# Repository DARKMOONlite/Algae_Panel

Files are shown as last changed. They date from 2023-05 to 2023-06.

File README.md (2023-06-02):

# Algae_Panel
repo for the storage of files related to the control and operation of an Algae Bio-panel at UTS

## [CAD ](/CAD/README.md)
### **Contains:**
- Solidworks Files
- STLs
- Drawings & Assembly Diagrams 
- Product Information

## [Software ](/Software/README.md)
### **Contains:**
- Installation & Setup Guide
- Doxygen Documentation
- Tips for making modifications & using placed systems.

---
### Visual Layout of Repo

```mermaid

graph LR;
    Repo-->CAD;
    Repo-->Software;
    CAD-->1[ElectrialModels];
    CAD-->2[Plumbing];
    CAD-->3[Previous DMMS Group];
    CAD-->4[Pump & Elec Mount];
    CAD-->5[Interior Mounts];
    Software-->Deprecated;
    Software-->AlgaeProject;
    AlgaeProject-->src;
    AlgaeProject-->lib;
    AlgaeProject-->include;
```

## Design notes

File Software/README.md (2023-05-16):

## Setup and installation

### 1. Setup VSCode & PlatformIO
1. download VSCode from the [link provided](https://code.visualstudio.com/).
2. once downloaded, run or open via cli using the `code` function.

3. Ensure you have access to a C Compiler, if not then follow [this tutorial](https://code.visualstudio.com/docs/languages/cpp) on the topic

4. once open, select the extensions tab, search and install the PlatformIO extension.

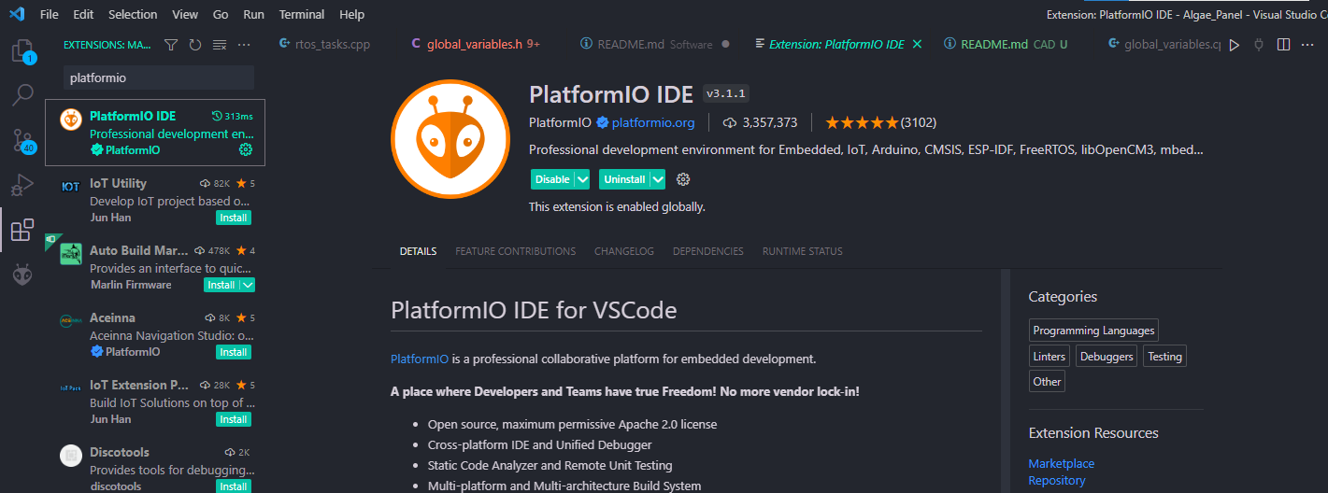
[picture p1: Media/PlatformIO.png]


5. Once downloaded open the [Algae Panel folder](/Software/Algae%20Project/) inside the Software folder inside the Algae Panel repo. this can be done via ```ctrl+K -> ctrl+O ```

6. Once done you should see the platformIO symbol in the primary bar  as well as a lot of new buttons down in the status bar.

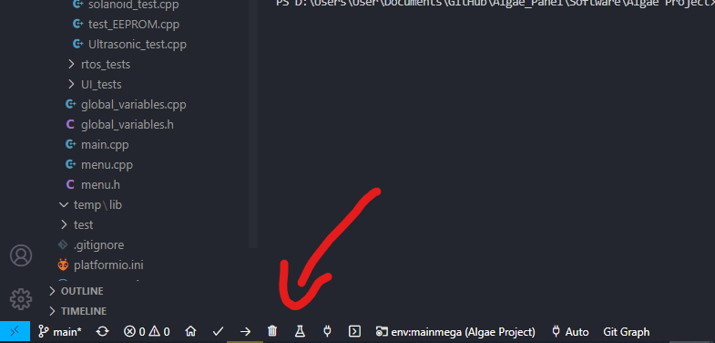
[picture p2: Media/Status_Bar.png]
 

These buttons starting from the tick do the following

| Symbol | Image | Description  |
| --- | --- |  ---- |
| Tick |  | builds the currently selected environment  |
| Arrow  |  | builds then uploads the selected environment to an attached board  |
| Trashcan  |  | cleans the currently attached arduino, replacing any code with a blink script  |
| Beaker  |  | runs all defined unit tests  |
| Plug  |  | Creates serial terminal connected to arduino  |
| terminal  |  | Creates a blank terminal (not very useful) |
| folder  |  | allows you to select the environment to build  |

---

## To run code
- create a new environment (inside the [platformio.ini file](/Software/Algae%20Project/platformio.ini)) or select a prexisting environment
- connect arduino to computer
- Upload the selected environment to the arduino via the Arrow Icon 

### Tips & Tricks

- if you're struggling to upload the file
    - ensure that no other terminal has access to the COM port (Open Serial Terminals are an often point of error)

    - if the arduino is constantly sending a stream of serial data back, you can press the power button to reset, then quickly upload before the arduino starts sending serial data

    - restart your computer

    - try another arduino

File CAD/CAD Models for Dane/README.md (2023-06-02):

READ ME

- Files ending in title ".WIP" are those that are: Work in Progress

- One file is an exploded Assembly

- One other file is a drawing file with BoM of different parts
- Furthermore you make need to zoom into .pdf in order to see the exploded parts

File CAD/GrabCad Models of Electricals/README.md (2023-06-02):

READ ME

- the following models in this file were downloaded from GrabCAD

- be aware that some of the models are outdated in terms of where the placement of the screw-in holes are

- this has affected the 3D print .STL file: FIXED_inside_mount

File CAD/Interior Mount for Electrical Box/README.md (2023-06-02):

READ ME

- file nameed: FIXED_inside_mount.SLDPRT is the best model for 3D printing:
- Be aware that the silos made will need to be reconfigured for each electrical component
- This is because the grabCAD models are not up to date as found out when the part was 3D printed
- Recommended to measure the screw-in holes on each electrical component & then reconfigure the file "FIXED_inside_mount" to new updated 

- File "Practice Assembly1" provides a visual layout of where each electrical component will sit on each silo. As previously stated if needed to be used for practical purposes, recommended that model is updated. 

- Schematics are provided. For further schematics of the electrical box itself, see link below: 
https://www.farnell.com/datasheets/1707001.pdf

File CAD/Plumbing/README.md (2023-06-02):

READ ME
- files added here are seperated into each folder based on the component
- furthermore there is a drawing provided for each one
- The majority of the components here were purchased at bunnings, some however needed to be purchased from specialty plumbing stores.
- Clear Hoses were used as its easy to see the flow of fluids through them, they do however have a low recomended maximum temperature limit, so in the future should be swapped for more robust piping.

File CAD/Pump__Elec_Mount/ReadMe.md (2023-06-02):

- This model is a simple design to affix the electrical box and the pump to the algae panel via hose clamps. 
- [This hose clamp](https://www.bunnings.com.au/kinetic-105-127mm-304-stainless-steel-hose-clamp_p0110744) was used, however it slightly too big, so a smaller one could be used instead.
- This model is effective however repeated installation and removal found that the design is quite weak, it could be redesigned an/or printed with a stronger material to make up for these discovered inefficiencies.

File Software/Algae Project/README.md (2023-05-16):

## A list of files has been proided as well as a short description on what they do and why/when you would want to make changes
---

| File | Description |
| --- | --- |
| [main.cpp](/Software/Algae%20Project/src/main.cpp) | Contains all running code|
| [menu.hpp/cpp](/Software/Algae%20Project/src/menu.h) | Contains definitions and declarations of menu system, custom functions related to the use of the menu are also placed here, if you want to add/rearrange the menu, it can be done by editing the menu class structure found here|
| [global_variables.h/cpp](/Software/Algae%20Project/src/global_variables.h) | Contains all global variable that need to be accessed from all other files, this includes EEPROM variables which should be defined here|
| [AlgaePanelRemote.hpp](/Software/Algae%20Project/include/AlgaePanelRemote.hpp) | Contains all definitions connected to controlling panel via remote, if you want to change remote, or add custom commands, you can do that by defining them here then using this inside the main switch case inside of main|
| [pin_definitions.hpp](/Software/Algae%20Project/include/pin_definitions.hpp) | Contains all pin defintions, if you want to add new sensors using new pins or change what pins are currently being used, add/modify them here (ensure that new pin has all needed functionality, etc: PWM, Analog In) |

## Libraries, there are 2 types of libraries used, platformIO maintained and User maintained.

- ### PlatformIO libraries can be found by opening the PlatformIO Homepage, then selecting Libraries in the lefthand submenu. 
    - These libraries have their own repositories that can be explored to view tutorials and examples on their use.
- ### Local libraries can be found inside the lib folder, the following is a list of libraries and their uses.

| Name | Description |
| --- | --- |
| DRI0050 | Manages the DRI0050 Pump PWM Controller |
| DS18B20 | Taken from Dane's original project, this reads the temperature of a one-wire temperature sensor |
| EEPPROM_Manager | contains an EEPROM_Variable and Manager class that allows for easier read write access to EEPROM memory |
| Simple_Menu | Contains a library that greatly simplifies menu creation and management, allows for variable modification and function calls |

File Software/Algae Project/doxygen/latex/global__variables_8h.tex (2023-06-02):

\hypertarget{global__variables_8h}{}\doxysection{src/global\+\_\+variables.h File Reference}
\label{global__variables_8h}\index{src/global\_variables.h@{src/global\_variables.h}}

Declares global variables to be used throughout the code.  

{\ttfamily \#include $<$Wire.\+h$>$}\newline
{\ttfamily \#include $<$Liquid\+Crystal\+\_\+\+I2\+C.\+h$>$}\newline
{\ttfamily \#include $<$Arduino\+STL.\+h$>$}\newline
{\ttfamily \#include $<$EEPROM\+\_\+\+Manager.\+h$>$}\newline
{\ttfamily \#include $<$menu.\+h$>$}\newline
{\ttfamily \#include $<$New\+Ping.\+h$>$}\newline
{\ttfamily \#include $<$DRI0050.\+h$>$}\newline
{\ttfamily \#include $<$Software\+Serial.\+h$>$}\newline
{\ttfamily \#include $<$DS18\+B20.\+h$>$}\newline
{\ttfamily \#include $<$pin\+\_\+definitions.\+hpp$>$}\newline
{\ttfamily \#include $<$Algae\+Panel\+Remote.\+hpp$>$}\newline
\doxysubsection*{Macros}
\begin{DoxyCompactItemize}
\item 
\#define \mbox{\hyperlink{global__variables_8h_a51cb8b878986ce3ff33493d99d02d7fc}{STATE\+\_\+\+RATE}}~2000
\item 
\#define \mbox{\hyperlink{global__variables_8h_a8c2953801f2011dc5901884b0e53ddd5}{SENSOR\+\_\+\+RATE}}~500
\item 
\#define \mbox{\hyperlink{global__variables_8h_a669d5bc07ca8e20ac1699a0b54db4817}{LCD\+\_\+\+RATE}}~500
\end{DoxyCompactItemize}
\doxysubsection*{Enumerations}
\begin{DoxyCompactItemize}
\item 
enum \mbox{\hyperlink{global__variables_8h_a7131f3b3e5d9a4980752d9ac3edaeea0}{Control\+\_\+\+State}} \{ \mbox{\hyperlink{global__variables_8h_a7131f3b3e5d9a4980752d9ac3edaeea0ad8a892b94d3a94ea861543c085ae782b}{Off}} =0
, \mbox{\hyperlink{global__variables_8h_a7131f3b3e5d9a4980752d9ac3edaeea0acad5010fb34447633f3139d69698a0f0}{Manual}} = 1
, \mbox{\hyperlink{global__variables_8h_a7131f3b3e5d9a4980752d9ac3edaeea0a9248ea5dc540b00adb523d1b86fc1389}{Automatic}} =2
 \}
\begin{DoxyCompactList}\small\item\em Control state for pump and solanoid. \end{DoxyCompactList}\end{DoxyCompactItemize}
\doxysubsection*{Variables}
\begin{DoxyCompactItemize}
\item 
const int \mbox{\hyperlink{global__variables_8h_ae0d7b8a179a4e00492f385d3e4c28875}{Cyclic\+\_\+\+Array\+\_\+\+Size}} = 10
\begin{DoxyCompactList}\small\item\em Cyclic\+\_\+\+Array Size;. \end{DoxyCompactList}\item 
uint8\+\_\+t \mbox{\hyperlink{global__variables_8h_a903dc10003a218620ea6bd4b59aca90f}{Cyclic\+\_\+\+Array\+\_\+\+Index}}
\begin{DoxyCompactList}\small\item\em Current Index of Arrays. \end{DoxyCompactList}\item 
int \mbox{\hyperlink{global__variables_8h_a4aa978fdd8b2af0060581b4cf057aa15}{Temp1}} \mbox{[}\mbox{\hyperlink{global__variables_8h_ae0d7b8a179a4e00492f385d3e4c28875}{Cyclic\+\_\+\+Array\+\_\+\+Size}}\mbox{]}
\item 
int \mbox{\hyperlink{global__variables_8h_a349ef976a3c80acee90c13d5274c1012}{Temp2}} \mbox{[}\mbox{\hyperlink{global__variables_8h_ae0d7b8a179a4e00492f385d3e4c28875}{Cyclic\+\_\+\+Array\+\_\+\+Size}}\mbox{]}
\item 
int \mbox{\hyperlink{global__variables_8h_a7a4f9da5a5b03e3b620a52b326c99171}{Sonar\+Dist1}} \mbox{[}\mbox{\hyperlink{global__variables_8h_ae0d7b8a179a4e00492f385d3e4c28875}{Cyclic\+\_\+\+Array\+\_\+\+Size}}\mbox{]}
\item 
int \mbox{\hyperlink{global__variables_8h_aa7423da4abe01b3d4e3ca46efe227ecc}{IRDist2}} \mbox{[}\mbox{\hyperlink{global__variables_8h_ae0d7b8a179a4e00492f385d3e4c28875}{Cyclic\+\_\+\+Array\+\_\+\+Size}}\mbox{]}
\item 
int \mbox{\hyperlink{global__variables_8h_ad2cddfbedfaa3c72c5ca3458123de2e6}{Temp1\+Average}}
\begin{DoxyCompactList}\small\item\em Current Rolling Average of value. \end{DoxyCompactList}\item 
int \mbox{\hyperlink{global__variables_8h_a98a9f68d7aba6c3f37ea78974a6cc324}{Temp2\+Average}}
\item 
int \mbox{\hyperlink{global__variables_8h_af8fa803a5d79a542c42ff09091f99f4c}{Sonar\+Average}}
\item 
int \mbox{\hyperlink{global__variables_8h_ac2983004a8cc1f5eade6ee043f323f2f}{IRAverage}}
\item 
\mbox{\hyperlink{global__variables_8h_a7131f3b3e5d9a4980752d9ac3edaeea0}{Control\+\_\+\+State}} \mbox{\hyperlink{global__variables_8h_a2192d4871d46cdc3fba65146088bdcb9}{Pump\+State}}
\item 
\mbox{\hyperlink{global__variables_8h_a7131f3b3e5d9a4980752d9ac3edaeea0}{Control\+\_\+\+State}} \mbox{\hyperlink{global__variables_8h_a73b179801e50a86199223fbf88f5c12e}{Solanoid\+State}}
\item 
\mbox{\hyperlink{global__variables_8h_a7131f3b3e5d9a4980752d9ac3edaeea0}{Control\+\_\+\+State}} \mbox{\hyperlink{global__variables_8h_a430bb6acf8cdf613e077c6a7f7c3d015}{prev\+Pump\+State}}
\item 
\mbox{\hyperlink{global__variables_8h_a7131f3b3e5d9a4980752d9ac3edaeea0}{Control\+\_\+\+State}} \mbox{\hyperlink{global__variables_8h_a48b73615b2cf62582fb4c47f95971475}{prev\+Solanoid\+State}}
\item 
uint32\+\_\+t \mbox{\hyperlink{global__variables_8h_a17ca7918be207c977093defdb63d0867}{last\+State\+Update}}
\item 
uint32\+\_\+t \mbox{\hyperlink{global__variables_8h_a549b506ca4e238d975211948ab268d2f}{last\+LCDUpdate}}
\item 
uint32\+\_\+t \mbox{\hyperlink{global__variables_8h_ae7075b28a1b0396f31bba96665f4e903}{last\+Sensor\+Update}}
\item 
Liquid\+Crystal\+\_\+\+I2C \mbox{\hyperlink{global__variables_8h_a0b3886fc5d22cd9c3db5f0da7b01a2ce}{lcd}}
\item 
\mbox{\hyperlink{class_e_e_p_r_o_m___manager}{EEPROM\+\_\+\+Manager}} \mbox{\hyperlink{global__variables_8h_ab06c714ee161cf34440fdb53fb5a6d24}{rom\+\_\+manager}}
\item 
\mbox{\hyperlink{class_e_e_p_r_o_m___variable}{EEPROM\+\_\+\+Variable}} \mbox{\hyperlink{global__variables_8h_a306cb999495057968c9ebdaca2d99c44}{manual\+\_\+dutycycle}}
\item 
\mbox{\hyperlink{class_e_e_p_r_o_m___variable}{EEPROM\+\_\+\+Variable}} \mbox{\hyperlink{global__variables_8h_a4402b0cf0598116bc1d727b00c74bf51}{autosave}}
\end{DoxyCompactItemize}

\doxysubsection{Detailed Description}
Declares global variables to be used throughout the code. 

\begin{DoxyAuthor}{Author}
your name (\href{mailto:you@domain.com}{\texttt{ you@domain.\+com}}) 
\end{DoxyAuthor}
\begin{DoxyVersion}{Version}
0.\+1 
\end{DoxyVersion}
\begin{DoxyDate}{Date}
2023-\/06-\/02
\end{DoxyDate}
\begin{DoxyCopyright}{Copyright}
Copyright (c) 2023 
\end{DoxyCopyright}

\doxysubsection{Macro Definition Documentation}
\mbox{\Hypertarget{global__variables_8h_a669d5bc07ca8e20ac1699a0b54db4817}\label{global__variables_8h_a669d5bc07ca8e20ac1699a0b54db4817}} 
\index{global\_variables.h@{global\_variables.h}!LCD\_RATE@{LCD\_RATE}}
\index{LCD\_RATE@{LCD\_RATE}!global\_variables.h@{global\_variables.h}}
\doxysubsubsection{\texorpdfstring{LCD\_RATE}{LCD\_RATE}}
{\footnotesize\ttfamily \#define LCD\+\_\+\+RATE~500}

\mbox{\Hypertarget{global__variables_8h_a8c2953801f2011dc5901884b0e53ddd5}\label{global__variables_8h_a8c2953801f2011dc5901884b0e53ddd5}} 
\index{global\_variables.h@{global\_variables.h}!SENSOR\_RATE@{SENSOR\_RATE}}
\index{SENSOR\_RATE@{SENSOR\_RATE}!global\_variables.h@{global\_variables.h}}
\doxysubsubsection{\texorpdfstring{SENSOR\_RATE}{SENSOR\_RATE}}
{\footnotesize\ttfamily \#define SENSOR\+\_\+\+RATE~500}

\mbox{\Hypertarget{global__variables_8h_a51cb8b878986ce3ff33493d99d02d7fc}\label{global__variables_8h_a51cb8b878986ce3ff33493d99d02d7fc}} 
\index{global\_variables.h@{global\_variables.h}!STATE\_RATE@{STATE\_RATE}}
\index{STATE\_RATE@{STATE\_RATE}!global\_variables.h@{global\_variables.h}}
\doxysubsubsection{\texorpdfstring{STATE\_RATE}{STATE\_RATE}}
{\footnotesize\ttfamily \#define STATE\+\_\+\+RATE~2000}

\doxysubsection{Enumeration Type Documentation}
\mbox{\Hypertarget{global__variables_8h_a7131f3b3e5d9a4980752d9ac3edaeea0}\label{global__variables_8h_a7131f3b3e5d9a4980752d9ac3edaeea0}} 
\index{global\_variables.h@{global\_variables.h}!Control\_State@{Control\_State}}
\index{Control\_State@{Control\_State}!global\_variables.h@{global\_variables.h}}
\doxysubsubsection{\texorpdfstring{Control\_State}{Control\_State}}
{\footnotesize\ttfamily enum \mbox{\hyperlink{global__variables_8h_a7131f3b3e5d9a4980752d9ac3edaeea0}{Control\+\_\+\+State}}}

Control state for pump and solanoid. 

\begin{DoxyEnumFields}{Enumerator}
\raisebox{\heightof{T}}[0pt][0pt]{\index{Off@{Off}!global\_variables.h@{global\_variables.h}}\index{global\_variables.h@{global\_variables.h}!Off@{Off}}}\mbox{\Hypertarget{global__variables_8h_a7131f3b3e5d9a4980752d9ac3edaeea0ad8a892b94d3a94ea861543c085ae782b}\label{global__variables_8h_a7131f3b3e5d9a4980752d9ac3edaeea0ad8a892b94d3a94ea861543c085ae782b}} 
Off&\\
\hline

\raisebox{\heightof{T}}[0pt][0pt]{\index{Manual@{Manual}!global\_variables.h@{global\_variables.h}}\index{global\_variables.h@{global\_variables.h}!Manual@{Manual}}}\mbox{\Hypertarget{global__variables_8h_a7131f3b3e5d9a4980752d9ac3edaeea0acad5010fb34447633f3139d69698a0f0}\label{global__variables_8h_a7131f3b3e5d9a4980752d9ac3edaeea0acad5010fb34447633f3139d69698a0f0}} 
Manual&\\
\hline

\raisebox{\heightof{T}}[0pt][0pt]{\index{Automatic@{Automatic}!global\_variables.h@{global\_variables.h}}\index{global\_variables.h@{global\_variables.h}!Automatic@{Automatic}}}\mbox{\Hypertarget{global__variables_8h_a7131f3b3e5d9a4980752d9ac3edaeea0a9248ea5dc540b00adb523d1b86fc1389}\label{global__variables_8h_a7131f3b3e5d9a4980752d9ac3edaeea0a9248ea5dc540b00adb523d1b86fc1389}} 
Automatic&\\
\hline

\end{DoxyEnumFields}

\doxysubsection{Variable Documentation}
\mbox{\Hypertarget{global__variables_8h_a4402b0cf0598116bc1d727b00c74bf51}\label{global__variables_8h_a4402b0cf0598116bc1d727b00c74bf51}} 
\index{global\_variables.h@{global\_variables.h}!autosave@{autosave}}
\index{autosave@{autosave}!global\_variables.h@{global\_variables.h}}
\doxysubsubsection{\texorpdfstring{autosave}{autosave}}
{\footnotesize\ttfamily \mbox{\hyperlink{class_e_e_p_r_o_m___variable}{EEPROM\+\_\+\+Variable}} autosave\hspace{0.3cm}{\ttfamily [extern]}}

\mbox{\Hypertarget{global__variables_8h_a903dc10003a218620ea6bd4b59aca90f}\label{global__variables_8h_a903dc10003a218620ea6bd4b59aca90f}} 
\index{global\_variables.h@{global\_variables.h}!Cyclic\_Array\_Index@{Cyclic\_Array\_Index}}
\index{Cyclic\_Array\_Index@{Cyclic\_Array\_Index}!global\_variables.h@{global\_variables.h}}
\doxysubsubsection{\texorpdfstring{Cyclic\_Array\_Index}{Cyclic\_Array\_Index}}
{\footnotesize\ttfamily uint8\+\_\+t Cyclic\+\_\+\+Array\+\_\+\+Index\hspace{0.3cm}{\ttfamily [extern]}}

Current Index of Arrays. 

\mbox{\Hypertarget{global__variables_8h_ae0d7b8a179a4e00492f385d3e4c28875}\label{global__variables_8h_ae0d7b8a179a4e00492f385d3e4c28875}} 
\index{global\_variables.h@{global\_variables.h}!Cyclic\_Array\_Size@{Cyclic\_Array\_Size}}
\index{Cyclic\_Array\_Size@{Cyclic\_Array\_Size}!global\_variables.h@{global\_variables.h}}
\doxysubsubsection{\texorpdfstring{Cyclic\_Array\_Size}{Cyclic\_Array\_Size}}
{\footnotesize\ttfamily const int Cyclic\+\_\+\+Array\+\_\+\+Size = 10}

Cyclic\+\_\+\+Array Size;. 

\mbox{\Hypertarget{global__variables_8h_ac2983004a8cc1f5eade6ee043f323f2f}\label{global__variables_8h_ac2983004a8cc1f5eade6ee043f323f2f}} 
\index{global\_variables.h@{global\_variables.h}!IRAverage@{IRAverage}}
\index{IRAverage@{IRAverage}!global\_variables.h@{global\_variables.h}}
\doxysubsubsection{\texorpdfstring{IRAverage}{IRAverage}}
{\footnotesize\ttfamily int IRAverage}

\mbox{\Hypertarget{global__variables_8h_aa7423da4abe01b3d4e3ca46efe227ecc}\label{global__variables_8h_aa7423da4abe01b3d4e3ca46efe227ecc}} 
\index{global\_variables.h@{global\_variables.h}!IRDist2@{IRDist2}}
\index{IRDist2@{IRDist2}!global\_variables.h@{global\_variables.h}}
\doxysubsubsection{\texorpdfstring{IRDist2}{IRDist2}}
{\footnotesize\ttfamily int IRDist2\mbox{[}\mbox{\hyperlink{global__variables_8h_ae0d7b8a179a4e00492f385d3e4c28875}{Cyclic\+\_\+\+Array\+\_\+\+Size}}\mbox{]}}

\mbox{\Hypertarget{global__variables_8h_a549b506ca4e238d975211948ab268d2f}\label{global__variables_8h_a549b506ca4e238d975211948ab268d2f}} 
\index{global\_variables.h@{global\_variables.h}!lastLCDUpdate@{lastLCDUpdate}}
\index{lastLCDUpdate@{lastLCDUpdate}!global\_variables.h@{global\_variables.h}}
\doxysubsubsection{\texorpdfstring{lastLCDUpdate}{lastLCDUpdate}}
{\footnotesize\ttfamily uint32\+\_\+t last\+LCDUpdate}

\mbox{\Hypertarget{global__variables_8h_ae7075b28a1b0396f31bba96665f4e903}\label{global__variables_8h_ae7075b28a1b0396f31bba96665f4e903}} 
\index{global\_variables.h@{global\_variables.h}!lastSensorUpdate@{lastSensorUpdate}}
\index{lastSensorUpdate@{lastSensorUpdate}!global\_variables.h@{global\_variables.h}}
\doxysubsubsection{\texorpdfstring{lastSensorUpdate}{lastSensorUpdate}}
{\footnotesize\ttfamily uint32\+\_\+t last\+Sensor\+Update}

\mbox{\Hypertarget{global__variables_8h_a17ca7918be207c977093defdb63d0867}\label{global__variables_8h_a17ca7918be207c977093defdb63d0867}} 
\index{global\_variables.h@{global\_variables.h}!lastStateUpdate@{lastStateUpdate}}
\index{lastStateUpdate@{lastStateUpdate}!global\_variables.h@{global\_variables.h}}
\doxysubsubsection{\texorpdfstring{lastStateUpdate}{lastStateUpdate}}
{\footnotesize\ttfamily uint32\+\_\+t last\+State\+Update\hspace{0.3cm}{\ttfamily [extern]}}

\mbox{\Hypertarget{global__variables_8h_a0b3886fc5d22cd9c3db5f0da7b01a2ce}\label{global__variables_8h_a0b3886fc5d22cd9c3db5f0da7b01a2ce}} 
\index{global\_variables.h@{global\_variables.h}!lcd@{lcd}}
\index{lcd@{lcd}!global\_variables.h@{global\_variables.h}}
\doxysubsubsection{\texorpdfstring{lcd}{lcd}}
{\footnotesize\ttfamily Liquid\+Crystal\+\_\+\+I2C lcd\hspace{0.3cm}{\ttfamily [extern]}}

\mbox{\Hypertarget{global__variables_8h_a306cb999495057968c9ebdaca2d99c44}\label{global__variables_8h_a306cb999495057968c9ebdaca2d99c44}} 
\index{global\_variables.h@{global\_variables.h}!manual\_dutycycle@{manual\_dutycycle}}
\index{manual\_dutycycle@{manual\_dutycycle}!global\_variables.h@{global\_variables.h}}
\doxysubsubsection{\texorpdfstring{manual\_dutycycle}{manual\_dutycycle}}
{\footnotesize\ttfamily \mbox{\hyperlink{class_e_e_p_r_o_m___variable}{EEPROM\+\_\+\+Variable}} manual\+\_\+dutycycle\hspace{0.3cm}{\ttfamily [extern]}}

\mbox{\Hypertarget{global__variables_8h_a430bb6acf8cdf613e077c6a7f7c3d015}\label{global__variables_8h_a430bb6acf8cdf613e077c6a7f7c3d015}} 
\index{global\_variables.h@{global\_variables.h}!prevPumpState@{prevPumpState}}
\index{prevPumpState@{prevPumpState}!global\_variables.h@{global\_variables.h}}
\doxysubsubsection{\texorpdfstring{prevPumpState}{prevPumpState}}
{\footnotesize\ttfamily \mbox{\hyperlink{global__variables_8h_a7131f3b3e5d9a4980752d9ac3edaeea0}{Control\+\_\+\+State}} prev\+Pump\+State}

\mbox{\Hypertarget{global__variables_8h_a48b73615b2cf62582fb4c47f95971475}\label{global__variables_8h_a48b73615b2cf62582fb4c47f95971475}} 
\index{global\_variables.h@{global\_variables.h}!prevSolanoidState@{prevSolanoidState}}
\index{prevSolanoidState@{prevSolanoidState}!global\_variables.h@{global\_variables.h}}
\doxysubsubsection{\texorpdfstring{prevSolanoidState}{prevSolanoidState}}
{\footnotesize\ttfamily \mbox{\hyperlink{global__variables_8h_a7131f3b3e5d9a4980752d9ac3edaeea0}{Control\+\_\+\+State}} prev\+Solanoid\+State}

\mbox{\Hypertarget{global__variables_8h_a2192d4871d46cdc3fba65146088bdcb9}\label{global__variables_8h_a2192d4871d46cdc3fba65146088bdcb9}} 
\index{global\_variables.h@{global\_variables.h}!PumpState@{PumpState}}
\index{PumpState@{PumpState}!global\_variables.h@{global\_variables.h}}
\doxysubsubsection{\texorpdfstring{PumpState}{PumpState}}
{\footnotesize\ttfamily \mbox{\hyperlink{global__variables_8h_a7131f3b3e5d9a4980752d9ac3edaeea0}{Control\+\_\+\+State}} Pump\+State\hspace{0.3cm}{\ttfamily [extern]}}

\mbox{\Hypertarget{global__variables_8h_ab06c714ee161cf34440fdb53fb5a6d24}\label{global__variables_8h_ab06c714ee161cf34440fdb53fb5a6d24}} 
\index{global\_variables.h@{global\_variables.h}!rom\_manager@{rom\_manager}}
\index{rom\_manager@{rom\_manager}!global\_variables.h@{global\_variables.h}}
\doxysubsubsection{\texorpdfstring{rom\_manager}{rom\_manager}}
{\footnotesize\ttfamily \mbox{\hyperlink{class_e_e_p_r_o_m___manager}{EEPROM\+\_\+\+Manager}} rom\+\_\+manager\hspace{0.3cm}{\ttfamily [extern]}}

\mbox{\Hypertarget{global__variables_8h_a73b179801e50a86199223fbf88f5c12e}\label{global__variables_8h_a73b179801e50a86199223fbf88f5c12e}} 
\index{global\_variables.h@{global\_variables.h}!SolanoidState@{SolanoidState}}
\index{SolanoidState@{SolanoidState}!global\_variables.h@{global\_variables.h}}
\doxysubsubsection{\texorpdfstring{SolanoidState}{SolanoidState}}
{\footnotesize\ttfamily \mbox{\hyperlink{global__variables_8h_a7131f3b3e5d9a4980752d9ac3edaeea0}{Control\+\_\+\+State}} Solanoid\+State}

\mbox{\Hypertarget{global__variables_8h_af8fa803a5d79a542c42ff09091f99f4c}\label{global__variables_8h_af8fa803a5d79a542c42ff09091f99f4c}} 
\index{global\_variables.h@{global\_variables.h}!SonarAverage@{SonarAverage}}
\index{SonarAverage@{SonarAverage}!global\_variables.h@{global\_variables.h}}
\doxysubsubsection{\texorpdfstring{SonarAverage}{SonarAverage}}
{\footnotesize\ttfamily int Sonar\+Average}

\mbox{\Hypertarget{global__variables_8h_a7a4f9da5a5b03e3b620a52b326c99171}\label{global__variables_8h_a7a4f9da5a5b03e3b620a52b326c99171}} 
\index{global\_variables.h@{global\_variables.h}!SonarDist1@{SonarDist1}}
\index{SonarDist1@{SonarDist1}!global\_variables.h@{global\_variables.h}}
\doxysubsubsection{\texorpdfstring{SonarDist1}{SonarDist1}}
{\footnotesize\ttfamily int Sonar\+Dist1\mbox{[}\mbox{\hyperlink{global__variables_8h_ae0d7b8a179a4e00492f385d3e4c28875}{Cyclic\+\_\+\+Array\+\_\+\+Size}}\mbox{]}}

\mbox{\Hypertarget{global__variables_8h_a4aa978fdd8b2af0060581b4cf057aa15}\label{global__variables_8h_a4aa978fdd8b2af0060581b4cf057aa15}} 
\index{global\_variables.h@{global\_variables.h}!Temp1@{Temp1}}
\index{Temp1@{Temp1}!global\_variables.h@{global\_variables.h}}
\doxysubsubsection{\texorpdfstring{Temp1}{Temp1}}
{\footnotesize\ttfamily int Temp1\mbox{[}\mbox{\hyperlink{global__variables_8h_ae0d7b8a179a4e00492f385d3e4c28875}{Cyclic\+\_\+\+Array\+\_\+\+Size}}\mbox{]}\hspace{0.3cm}{\ttfamily [extern]}}

\mbox{\Hypertarget{global__variables_8h_ad2cddfbedfaa3c72c5ca3458123de2e6}\label{global__variables_8h_ad2cddfbedfaa3c72c5ca3458123de2e6}} 
\index{global\_variables.h@{global\_variables.h}!Temp1Average@{Temp1Average}}
\index{Temp1Average@{Temp1Average}!global\_variables.h@{global\_variables.h}}
\doxysubsubsection{\texorpdfstring{Temp1Average}{Temp1Average}}
{\footnotesize\ttfamily int Temp1\+Average\hspace{0.3cm}{\ttfamily [extern]}}

Current Rolling Average of value. 

\mbox{\Hypertarget{global__variables_8h_a349ef976a3c80acee90c13d5274c1012}\label{global__variables_8h_a349ef976a3c80acee90c13d5274c1012}} 
\index{global\_variables.h@{global\_variables.h}!Temp2@{Temp2}}
\index{Temp2@{Temp2}!global\_variables.h@{global\_variables.h}}
\doxysubsubsection{\texorpdfstring{Temp2}{Temp2}}
{\footnotesize\ttfamily int Temp2\mbox{[}\mbox{\hyperlink{global__variables_8h_ae0d7b8a179a4e00492f385d3e4c28875}{Cyclic\+\_\+\+Array\+\_\+\+Size}}\mbox{]}}

\mbox{\Hypertarget{global__variables_8h_a98a9f68d7aba6c3f37ea78974a6cc324}\label{global__variables_8h_a98a9f68d7aba6c3f37ea78974a6cc324}} 
\index{global\_variables.h@{global\_variables.h}!Temp2Average@{Temp2Average}}
\index{Temp2Average@{Temp2Average}!global\_variables.h@{global\_variables.h}}
\doxysubsubsection{\texorpdfstring{Temp2Average}{Temp2Average}}
{\footnotesize\ttfamily int Temp2\+Average}

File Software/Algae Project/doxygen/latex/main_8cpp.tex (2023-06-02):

\hypertarget{main_8cpp}{}\doxysection{src/main.cpp File Reference}
\label{main_8cpp}\index{src/main.cpp@{src/main.cpp}}

Main file, to run either select the main or mainmega environments inside platformio main may not run due to the large size of the menu inside.  

{\ttfamily \#include $<$Wire.\+h$>$}\newline
{\ttfamily \#include $<$global\+\_\+variables.\+h$>$}\newline
{\ttfamily \#include $<$Arduino.\+h$>$}\newline
{\ttfamily \#include $<$IRremote.\+h$>$}\newline
\doxysubsection*{Functions}
\begin{DoxyCompactItemize}
\item 
void \mbox{\hyperlink{main_8cpp_af9cf4ef7ebebb6c181594d5a1c6dc3a2}{Update\+\_\+\+Sensor\+\_\+\+State}} ()
\item 
void \mbox{\hyperlink{main_8cpp_a4be994af2b57ccfe32022694d07b4082}{Update\+\_\+\+Control\+\_\+\+State}} ()
\item 
New\+Ping \mbox{\hyperlink{main_8cpp_aa3890dc13ad641f783b713ac4bd4a749}{Sonar1}} (\mbox{\hyperlink{pin__definitions_8hpp_a9a54be5fe92c6d16578982bf6cecd891}{SSensor\+Pin1}}, \mbox{\hyperlink{pin__definitions_8hpp_aea99235fa3eef529e3ca42c55036d49a}{Sonar\+Echo\+Pin}}, 400)
\item 
New\+Ping \mbox{\hyperlink{main_8cpp_a13056dab98115394b132ce9e388cd66f}{Sonar2}} (\mbox{\hyperlink{pin__definitions_8hpp_acbebe49963630ffe7894925f9af6929e}{SSensor\+Pin2}}, \mbox{\hyperlink{pin__definitions_8hpp_aea99235fa3eef529e3ca42c55036d49a}{Sonar\+Echo\+Pin}}, 400)
\item 
IRrecv \mbox{\hyperlink{main_8cpp_a719f315363a42d399582066b011803a0}{irrecv}} (\mbox{\hyperlink{pin__definitions_8hpp_aca6f3616097e746f44b630d09fa99c98}{IRRXPin}})
\item 
void \mbox{\hyperlink{main_8cpp_a4fc01d736fe50cf5b977f755b675f11d}{setup}} ()
\item 
void \mbox{\hyperlink{main_8cpp_afe461d27b9c48d5921c00d521181f12f}{loop}} ()
\end{DoxyCompactItemize}
\doxysubsection*{Variables}
\begin{DoxyCompactItemize}
\item 
\mbox{\hyperlink{class_d_s18_b20}{DS18\+B20}} \mbox{\hyperlink{main_8cpp_abf193c5fdc2f45cdabb593b689213741}{Temp\+Sensor1}} (\mbox{\hyperlink{pin__definitions_8hpp_a671f1d97cbed333ba37efc31c19176d4}{TSensor\+Pin1}})
\item 
\mbox{\hyperlink{class_d_s18_b20}{DS18\+B20}} \mbox{\hyperlink{main_8cpp_ae6a8ea5c1f475f84c3a2fd12ccca81a1}{Temp\+Sensor2}} (\mbox{\hyperlink{pin__definitions_8hpp_a1b12e63467a86c1176ada2ca6dfd6ba1}{TSensor\+Pin2}})
\item 
\mbox{\hyperlink{class_d_r_i0050}{DRI0050}} \mbox{\hyperlink{main_8cpp_a8b8365b51c26f340cc7c21a6eddc1146}{Pump\+Controller}} (\mbox{\hyperlink{pin__definitions_8hpp_ae547f2a53633fd8b936d4dc812447c17}{Pump\+Tx\+Pin}}, \mbox{\hyperlink{pin__definitions_8hpp_a98300bbbce3a65d992bbf4be3a84600b}{Pump\+Rx\+Pin}})
\end{DoxyCompactItemize}

\doxysubsection{Detailed Description}
Main file, to run either select the main or mainmega environments inside platformio main may not run due to the large size of the menu inside. 

\begin{DoxyAuthor}{Author}
Sebastian Schroder 
\end{DoxyAuthor}

\doxysubsection{Function Documentation}
\mbox{\Hypertarget{main_8cpp_a719f315363a42d399582066b011803a0}\label{main_8cpp_a719f315363a42d399582066b011803a0}} 
\index{main.cpp@{main.cpp}!irrecv@{irrecv}}
\index{irrecv@{irrecv}!main.cpp@{main.cpp}}
\doxysubsubsection{\texorpdfstring{irrecv()}{irrecv()}}
{\footnotesize\ttfamily IRrecv irrecv (\begin{DoxyParamCaption}\item[{\mbox{\hyperlink{pin__definitions_8hpp_aca6f3616097e746f44b630d09fa99c98}{IRRXPin}}}]{ }\end{DoxyParamCaption})}

\mbox{\Hypertarget{main_8cpp_afe461d27b9c48d5921c00d521181f12f}\label{main_8cpp_afe461d27b9c48d5921c00d521181f12f}} 
\index{main.cpp@{main.cpp}!loop@{loop}}
\index{loop@{loop}!main.cpp@{main.cpp}}
\doxysubsubsection{\texorpdfstring{loop()}{loop()}}
{\footnotesize\ttfamily void loop (\begin{DoxyParamCaption}{ }\end{DoxyParamCaption})}

\mbox{\Hypertarget{main_8cpp_a4fc01d736fe50cf5b977f755b675f11d}\label{main_8cpp_a4fc01d736fe50cf5b977f755b675f11d}} 
\index{main.cpp@{main.cpp}!setup@{setup}}
\index{setup@{setup}!main.cpp@{main.cpp}}
\doxysubsubsection{\texorpdfstring{setup()}{setup()}}
{\footnotesize\ttfamily void setup (\begin{DoxyParamCaption}{ }\end{DoxyParamCaption})}

\mbox{\Hypertarget{main_8cpp_aa3890dc13ad641f783b713ac4bd4a749}\label{main_8cpp_aa3890dc13ad641f783b713ac4bd4a749}} 
\index{main.cpp@{main.cpp}!Sonar1@{Sonar1}}
\index{Sonar1@{Sonar1}!main.cpp@{main.cpp}}
\doxysubsubsection{\texorpdfstring{Sonar1()}{Sonar1()}}
{\footnotesize\ttfamily New\+Ping Sonar1 (\begin{DoxyParamCaption}\item[{\mbox{\hyperlink{pin__definitions_8hpp_a9a54be5fe92c6d16578982bf6cecd891}{SSensor\+Pin1}}}]{,  }\item[{\mbox{\hyperlink{pin__definitions_8hpp_aea99235fa3eef529e3ca42c55036d49a}{Sonar\+Echo\+Pin}}}]{,  }\item[{400}]{ }\end{DoxyParamCaption})}

\mbox{\Hypertarget{main_8cpp_a13056dab98115394b132ce9e388cd66f}\label{main_8cpp_a13056dab98115394b132ce9e388cd66f}} 
\index{main.cpp@{main.cpp}!Sonar2@{Sonar2}}
\index{Sonar2@{Sonar2}!main.cpp@{main.cpp}}
\doxysubsubsection{\texorpdfstring{Sonar2()}{Sonar2()}}
{\footnotesize\ttfamily New\+Ping Sonar2 (\begin{DoxyParamCaption}\item[{\mbox{\hyperlink{pin__definitions_8hpp_acbebe49963630ffe7894925f9af6929e}{SSensor\+Pin2}}}]{,  }\item[{\mbox{\hyperlink{pin__definitions_8hpp_aea99235fa3eef529e3ca42c55036d49a}{Sonar\+Echo\+Pin}}}]{,  }\item[{400}]{ }\end{DoxyParamCaption})}

\mbox{\Hypertarget{main_8cpp_a4be994af2b57ccfe32022694d07b4082}\label{main_8cpp_a4be994af2b57ccfe32022694d07b4082}} 
\index{main.cpp@{main.cpp}!Update\_Control\_State@{Update\_Control\_State}}
\index{Update\_Control\_State@{Update\_Control\_State}!main.cpp@{main.cpp}}
\doxysubsubsection{\texorpdfstring{Update\_Control\_State()}{Update\_Control\_State()}}
{\footnotesize\ttfamily void Update\+\_\+\+Control\+\_\+\+State (\begin{DoxyParamCaption}{ }\end{DoxyParamCaption})}

\mbox{\Hypertarget{main_8cpp_af9cf4ef7ebebb6c181594d5a1c6dc3a2}\label{main_8cpp_af9cf4ef7ebebb6c181594d5a1c6dc3a2}} 
\index{main.cpp@{main.cpp}!Update\_Sensor\_State@{Update\_Sensor\_State}}
\index{Update\_Sensor\_State@{Update\_Sensor\_State}!main.cpp@{main.cpp}}
\doxysubsubsection{\texorpdfstring{Update\_Sensor\_State()}{Update\_Sensor\_State()}}
{\footnotesize\ttfamily void Update\+\_\+\+Sensor\+\_\+\+State (\begin{DoxyParamCaption}{ }\end{DoxyParamCaption})}

\doxysubsection{Variable Documentation}
\mbox{\Hypertarget{main_8cpp_a8b8365b51c26f340cc7c21a6eddc1146}\label{main_8cpp_a8b8365b51c26f340cc7c21a6eddc1146}} 
\index{main.cpp@{main.cpp}!PumpController@{PumpController}}
\index{PumpController@{PumpController}!main.cpp@{main.cpp}}
\doxysubsubsection{\texorpdfstring{PumpController}{PumpController}}
{\footnotesize\ttfamily \mbox{\hyperlink{class_d_r_i0050}{DRI0050}} Pump\+Controller(\mbox{\hyperlink{pin__definitions_8hpp_ae547f2a53633fd8b936d4dc812447c17}{Pump\+Tx\+Pin}}, \mbox{\hyperlink{pin__definitions_8hpp_a98300bbbce3a65d992bbf4be3a84600b}{Pump\+Rx\+Pin}}) (\begin{DoxyParamCaption}\item[{\mbox{\hyperlink{pin__definitions_8hpp_ae547f2a53633fd8b936d4dc812447c17}{Pump\+Tx\+Pin}}}]{,  }\item[{\mbox{\hyperlink{pin__definitions_8hpp_a98300bbbce3a65d992bbf4be3a84600b}{Pump\+Rx\+Pin}}}]{ }\end{DoxyParamCaption})}

\mbox{\Hypertarget{main_8cpp_abf193c5fdc2f45cdabb593b689213741}\label{main_8cpp_abf193c5fdc2f45cdabb593b689213741}} 
\index{main.cpp@{main.cpp}!TempSensor1@{TempSensor1}}
\index{TempSensor1@{TempSensor1}!main.cpp@{main.cpp}}
\doxysubsubsection{\texorpdfstring{TempSensor1}{TempSensor1}}
{\footnotesize\ttfamily \mbox{\hyperlink{class_d_s18_b20}{DS18\+B20}} Temp\+Sensor1(\mbox{\hyperlink{pin__definitions_8hpp_a671f1d97cbed333ba37efc31c19176d4}{TSensor\+Pin1}}) (\begin{DoxyParamCaption}\item[{\mbox{\hyperlink{pin__definitions_8hpp_a671f1d97cbed333ba37efc31c19176d4}{TSensor\+Pin1}}}]{ }\end{DoxyParamCaption})}

\mbox{\Hypertarget{main_8cpp_ae6a8ea5c1f475f84c3a2fd12ccca81a1}\label{main_8cpp_ae6a8ea5c1f475f84c3a2fd12ccca81a1}} 
\index{main.cpp@{main.cpp}!TempSensor2@{TempSensor2}}
\index{TempSensor2@{TempSensor2}!main.cpp@{main.cpp}}
\doxysubsubsection{\texorpdfstring{TempSensor2}{TempSensor2}}
{\footnotesize\ttfamily \mbox{\hyperlink{class_d_s18_b20}{DS18\+B20}} Temp\+Sensor2(\mbox{\hyperlink{pin__definitions_8hpp_a1b12e63467a86c1176ada2ca6dfd6ba1}{TSensor\+Pin2}}) (\begin{DoxyParamCaption}\item[{\mbox{\hyperlink{pin__definitions_8hpp_a1b12e63467a86c1176ada2ca6dfd6ba1}{TSensor\+Pin2}}}]{ }\end{DoxyParamCaption})}

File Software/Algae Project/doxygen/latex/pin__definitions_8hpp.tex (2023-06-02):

\hypertarget{pin__definitions_8hpp}{}\doxysection{include/pin\+\_\+definitions.hpp File Reference}
\label{pin__definitions_8hpp}\index{include/pin\_definitions.hpp@{include/pin\_definitions.hpp}}

Use this document to define all Pins used in the main code in the \mbox{\hyperlink{menu_8cpp}{menu.\+cpp}} file inside the Menu\+\_\+\+IR\+\_\+\+Input function.  

{\ttfamily \#include $<$Arduino.\+h$>$}\newline
\doxysubsection*{Macros}
\begin{DoxyCompactItemize}
\item 
\#define \mbox{\hyperlink{pin__definitions_8hpp_a671f1d97cbed333ba37efc31c19176d4}{TSensor\+Pin1}}~12
\item 
\#define \mbox{\hyperlink{pin__definitions_8hpp_a1b12e63467a86c1176ada2ca6dfd6ba1}{TSensor\+Pin2}}~13
\item 
\#define \mbox{\hyperlink{pin__definitions_8hpp_a9a54be5fe92c6d16578982bf6cecd891}{SSensor\+Pin1}}~A3
\item 
\#define \mbox{\hyperlink{pin__definitions_8hpp_acbebe49963630ffe7894925f9af6929e}{SSensor\+Pin2}}~A4
\item 
\#define \mbox{\hyperlink{pin__definitions_8hpp_aea99235fa3eef529e3ca42c55036d49a}{Sonar\+Echo\+Pin}}~A2
\item 
\#define \mbox{\hyperlink{pin__definitions_8hpp_ae547f2a53633fd8b936d4dc812447c17}{Pump\+Tx\+Pin}}~9
\item 
\#define \mbox{\hyperlink{pin__definitions_8hpp_a98300bbbce3a65d992bbf4be3a84600b}{Pump\+Rx\+Pin}}~10
\item 
\#define \mbox{\hyperlink{pin__definitions_8hpp_a716c109071dabc5172b8b12c5795a1ae}{Solanoid\+Pin1}}~22
\item 
\#define \mbox{\hyperlink{pin__definitions_8hpp_a0e34ce111e1eeb07757bd097cc23b761}{Solanoid\+Pin2}}~24
\item 
\#define \mbox{\hyperlink{pin__definitions_8hpp_aca6f3616097e746f44b630d09fa99c98}{IRRXPin}}~11
\end{DoxyCompactItemize}

\doxysubsection{Detailed Description}
Use this document to define all Pins used in the main code in the \mbox{\hyperlink{menu_8cpp}{menu.\+cpp}} file inside the Menu\+\_\+\+IR\+\_\+\+Input function. 

\begin{DoxyAuthor}{Author}
Sebastian Schroder 
\end{DoxyAuthor}
\begin{DoxyVersion}{Version}
0.\+1 
\end{DoxyVersion}
\begin{DoxyDate}{Date}
2023-\/06-\/02
\end{DoxyDate}
\begin{DoxyCopyright}{Copyright}
Copyright (c) 2023 
\end{DoxyCopyright}

\doxysubsection{Macro Definition Documentation}
\mbox{\Hypertarget{pin__definitions_8hpp_aca6f3616097e746f44b630d09fa99c98}\label{pin__definitions_8hpp_aca6f3616097e746f44b630d09fa99c98}} 
\index{pin\_definitions.hpp@{pin\_definitions.hpp}!IRRXPin@{IRRXPin}}
\index{IRRXPin@{IRRXPin}!pin\_definitions.hpp@{pin\_definitions.hpp}}
\doxysubsubsection{\texorpdfstring{IRRXPin}{IRRXPin}}
{\footnotesize\ttfamily \#define IRRXPin~11}

\mbox{\Hypertarget{pin__definitions_8hpp_a98300bbbce3a65d992bbf4be3a84600b}\label{pin__definitions_8hpp_a98300bbbce3a65d992bbf4be3a84600b}} 
\index{pin\_definitions.hpp@{pin\_definitions.hpp}!PumpRxPin@{PumpRxPin}}
\index{PumpRxPin@{PumpRxPin}!pin\_definitions.hpp@{pin\_definitions.hpp}}
\doxysubsubsection{\texorpdfstring{PumpRxPin}{PumpRxPin}}
{\footnotesize\ttfamily \#define Pump\+Rx\+Pin~10}

\mbox{\Hypertarget{pin__definitions_8hpp_ae547f2a53633fd8b936d4dc812447c17}\label{pin__definitions_8hpp_ae547f2a53633fd8b936d4dc812447c17}} 
\index{pin\_definitions.hpp@{pin\_definitions.hpp}!PumpTxPin@{PumpTxPin}}
\index{PumpTxPin@{PumpTxPin}!pin\_definitions.hpp@{pin\_definitions.hpp}}
\doxysubsubsection{\texorpdfstring{PumpTxPin}{PumpTxPin}}
{\footnotesize\ttfamily \#define Pump\+Tx\+Pin~9}

\mbox{\Hypertarget{pin__definitions_8hpp_a716c109071dabc5172b8b12c5795a1ae}\label{pin__definitions_8hpp_a716c109071dabc5172b8b12c5795a1ae}} 
\index{pin\_definitions.hpp@{pin\_definitions.hpp}!SolanoidPin1@{SolanoidPin1}}
\index{SolanoidPin1@{SolanoidPin1}!pin\_definitions.hpp@{pin\_definitions.hpp}}
\doxysubsubsection{\texorpdfstring{SolanoidPin1}{SolanoidPin1}}
{\footnotesize\ttfamily \#define Solanoid\+Pin1~22}

\mbox{\Hypertarget{pin__definitions_8hpp_a0e34ce111e1eeb07757bd097cc23b761}\label{pin__definitions_8hpp_a0e34ce111e1eeb07757bd097cc23b761}} 
\index{pin\_definitions.hpp@{pin\_definitions.hpp}!SolanoidPin2@{SolanoidPin2}}
\index{SolanoidPin2@{SolanoidPin2}!pin\_definitions.hpp@{pin\_definitions.hpp}}
\doxysubsubsection{\texorpdfstring{SolanoidPin2}{SolanoidPin2}}
{\footnotesize\ttfamily \#define Solanoid\+Pin2~24}

\mbox{\Hypertarget{pin__definitions_8hpp_aea99235fa3eef529e3ca42c55036d49a}\label{pin__definitions_8hpp_aea99235fa3eef529e3ca42c55036d49a}} 
\index{pin\_definitions.hpp@{pin\_definitions.hpp}!SonarEchoPin@{SonarEchoPin}}
\index{SonarEchoPin@{SonarEchoPin}!pin\_definitions.hpp@{pin\_definitions.hpp}}
\doxysubsubsection{\texorpdfstring{SonarEchoPin}{SonarEchoPin}}
{\footnotesize\ttfamily \#define Sonar\+Echo\+Pin~A2}

\mbox{\Hypertarget{pin__definitions_8hpp_a9a54be5fe92c6d16578982bf6cecd891}\label{pin__definitions_8hpp_a9a54be5fe92c6d16578982bf6cecd891}} 
\index{pin\_definitions.hpp@{pin\_definitions.hpp}!SSensorPin1@{SSensorPin1}}
\index{SSensorPin1@{SSensorPin1}!pin\_definitions.hpp@{pin\_definitions.hpp}}
\doxysubsubsection{\texorpdfstring{SSensorPin1}{SSensorPin1}}
{\footnotesize\ttfamily \#define SSensor\+Pin1~A3}

\mbox{\Hypertarget{pin__definitions_8hpp_acbebe49963630ffe7894925f9af6929e}\label{pin__definitions_8hpp_acbebe49963630ffe7894925f9af6929e}} 
\index{pin\_definitions.hpp@{pin\_definitions.hpp}!SSensorPin2@{SSensorPin2}}
\index{SSensorPin2@{SSensorPin2}!pin\_definitions.hpp@{pin\_definitions.hpp}}
\doxysubsubsection{\texorpdfstring{SSensorPin2}{SSensorPin2}}
{\footnotesize\ttfamily \#define SSensor\+Pin2~A4}

\mbox{\Hypertarget{pin__definitions_8hpp_a671f1d97cbed333ba37efc31c19176d4}\label{pin__definitions_8hpp_a671f1d97cbed333ba37efc31c19176d4}} 
\index{pin\_definitions.hpp@{pin\_definitions.hpp}!TSensorPin1@{TSensorPin1}}
\index{TSensorPin1@{TSensorPin1}!pin\_definitions.hpp@{pin\_definitions.hpp}}
\doxysubsubsection{\texorpdfstring{TSensorPin1}{TSensorPin1}}
{\footnotesize\ttfamily \#define TSensor\+Pin1~12}

\mbox{\Hypertarget{pin__definitions_8hpp_a1b12e63467a86c1176ada2ca6dfd6ba1}\label{pin__definitions_8hpp_a1b12e63467a86c1176ada2ca6dfd6ba1}} 
\index{pin\_definitions.hpp@{pin\_definitions.hpp}!TSensorPin2@{TSensorPin2}}
\index{TSensorPin2@{TSensorPin2}!pin\_definitions.hpp@{pin\_definitions.hpp}}
\doxysubsubsection{\texorpdfstring{TSensorPin2}{TSensorPin2}}
{\footnotesize\ttfamily \#define TSensor\+Pin2~13}

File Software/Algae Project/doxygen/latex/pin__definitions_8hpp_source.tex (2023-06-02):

\hypertarget{pin__definitions_8hpp_source}{}\doxysection{pin\+\_\+definitions.\+hpp}
\label{pin__definitions_8hpp_source}\index{include/pin\_definitions.hpp@{include/pin\_definitions.hpp}}
\mbox{\hyperlink{pin__definitions_8hpp}{Go to the documentation of this file.}}
\begin{DoxyCode}{0}
\DoxyCodeLine{1 }
\DoxyCodeLine{12 \textcolor{preprocessor}{\#ifndef PIN\_DEFINITIONS\_H}}
\DoxyCodeLine{13 \textcolor{preprocessor}{\#define PIN\_DEFINITIONS\_H}}
\DoxyCodeLine{14 \textcolor{preprocessor}{\#include <Arduino.h>}}
\DoxyCodeLine{15 }
\DoxyCodeLine{16 }
\DoxyCodeLine{17 }
\DoxyCodeLine{18 }
\DoxyCodeLine{19 }
\DoxyCodeLine{20 }
\DoxyCodeLine{21 \textcolor{comment}{// -\/-\/-\/-\/-\/-\/-\/-\/-\/-\/-\/-\/-\/-\/-\/-\/-\/-\/-\/-\/-\/-\/-\/-\/-\/-\/       SENSORS     -\/-\/-\/-\/-\/-\/-\/-\/-\/-\/-\/-\/-\/-\/-\/-\/-\/-\/-\/-\/-\/-\/-\/-\/-\/-\/-\/-\/-\/-\/}}
\DoxyCodeLine{22 \textcolor{preprocessor}{\# define TSensorPin1 12}}
\DoxyCodeLine{23 \textcolor{preprocessor}{\#define TSensorPin2 13}}
\DoxyCodeLine{24 \textcolor{preprocessor}{\#define SSensorPin1 A3}}
\DoxyCodeLine{25 \textcolor{preprocessor}{\#define SSensorPin2 A4}}
\DoxyCodeLine{26 \textcolor{preprocessor}{\#define SonarEchoPin A2}}
\DoxyCodeLine{27 }
\DoxyCodeLine{28 }
\DoxyCodeLine{29 }
\DoxyCodeLine{30 \textcolor{comment}{//-\/-\/-\/-\/-\/-\/-\/-\/-\/-\/-\/-\/-\/-\/-\/-\/-\/-\/-\/-\/-\/-\/-\/-\/-\/-\/-\/-\/-\/-\/        CONTROL     -\/-\/-\/-\/-\/-\/-\/-\/-\/-\/-\/-\/-\/-\/-\/-\/-\/-\/-\/-\/-\/-\/-\/-\/-\/-\/-\/-\/-\/-\/-\/-\/}}
\DoxyCodeLine{31 \textcolor{preprocessor}{\#define PumpTxPin 9}}
\DoxyCodeLine{32 \textcolor{preprocessor}{\#define PumpRxPin 10}}
\DoxyCodeLine{33 }
\DoxyCodeLine{34 \textcolor{preprocessor}{\#define SolanoidPin1 22}}
\DoxyCodeLine{35 \textcolor{preprocessor}{\#define SolanoidPin2 24 }\textcolor{comment}{// emergency pin for use with the pump until the pwm motor controller board arrives }}
\DoxyCodeLine{36 }
\DoxyCodeLine{37 }
\DoxyCodeLine{38 \textcolor{comment}{//-\/-\/-\/-\/-\/-\/-\/-\/-\/-\/-\/-\/-\/-\/-\/-\/-\/-\/-\/-\/-\/-\/-\/-\/-\/-\/-\/-\/-\/-\/        UI      -\/-\/-\/-\/-\/-\/-\/-\/-\/-\/-\/-\/-\/-\/-\/-\/-\/-\/-\/-\/-\/-\/-\/-\/-\/-\/-\/-\/-\/-\/}}
\DoxyCodeLine{39 }
\DoxyCodeLine{40 \textcolor{preprocessor}{\#define IRRXPin 11}}
\DoxyCodeLine{41 }
\DoxyCodeLine{42 }
\DoxyCodeLine{43 \textcolor{comment}{// -\/-\/-\/-\/-\/-\/-\/-\/-\/-\/-\/-\/-\/-\/-\/-\/-\/-\/-\/-\/-\/-\/-\/-\/-\/-\/-\/-\/     DEPRECATED      -\/-\/-\/-\/-\/-\/-\/-\/-\/-\/-\/-\/-\/-\/-\/-\/-\/-\/-\/-\/-\/-\/-\/-\/-\/-\/-\/-\/-\/-\/-\/-\/-\/}}
\DoxyCodeLine{44 \textcolor{comment}{// \#define xinput  A0}}
\DoxyCodeLine{45 \textcolor{comment}{// \#define yinput = A1}}
\DoxyCodeLine{46 \textcolor{comment}{// \#define Button = 8}}
\DoxyCodeLine{47 }
\DoxyCodeLine{48 \textcolor{preprocessor}{\#endif}}

\end{DoxyCode}

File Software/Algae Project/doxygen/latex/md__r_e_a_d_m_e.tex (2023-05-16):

\tabulinesep=1mm
\begin{longtabu}spread 0pt [c]{*{2}{|X[-1]}|}
\hline
\PBS\centering \cellcolor{\tableheadbgcolor}\textbf{ File   }&\PBS\centering \cellcolor{\tableheadbgcolor}\textbf{ Description    }\\\cline{1-2}
\endfirsthead
\hline
\endfoot
\hline
\PBS\centering \cellcolor{\tableheadbgcolor}\textbf{ File   }&\PBS\centering \cellcolor{\tableheadbgcolor}\textbf{ Description    }\\\cline{1-2}
\endhead
\href{/Software/Algae\%20Project/src/main.cpp}{\texttt{ main.\+cpp}}   &Contains all running code    \\\cline{1-2}
\href{/Software/Algae\%20Project/src/menu.h}{\texttt{ menu.\+hpp/cpp}}   &Contains definitions and declarations of menu system, custom functions related to the use of the menu are also placed here, if you want to add/rearrange the menu, it can be done by editing the menu class structure found here    \\\cline{1-2}
\href{/Software/Algae\%20Project/src/global_variables.h}{\texttt{ global\+\_\+variables.\+h/cpp}}   &Contains all global variable that need to be accessed from all other files, this includes EEPROM variables which should be defined here    \\\cline{1-2}
\href{/Software/Algae\%20Project/include/AlgaePanelRemote.hpp}{\texttt{ Algae\+Panel\+Remote.\+hpp}}   &Contains all definitions connected to controlling panel via remote, if you want to change remote, or add custom commands, you can do that by defining them here then using this inside the main switch case inside of main    \\\cline{1-2}
\href{/Software/Algae\%20Project/include/pin_definitions.hpp}{\texttt{ pin\+\_\+definitions.\+hpp}}   &Contains all pin defintions, if you want to add new sensors using new pins or change what pins are currently being used, add/modify them here (ensure that new pin has all needed functionality, etc\+: PWM, Analog In)   \\\cline{1-2}
\end{longtabu}
\hypertarget{md__r_e_a_d_m_e_autotoc_md0}{}\doxysection{Libraries, there are 2 types of libraries used, platform\+IO maintained and User maintained.}\label{md__r_e_a_d_m_e_autotoc_md0}

\begin{DoxyItemize}
\item \#\#\# Platform\+IO libraries can be found by opening the Platform\+IO Homepage, then selecting Libraries in the lefthand submenu.
\begin{DoxyItemize}
\item These libraries have their own repositories that can be explored to view tutorials and examples on their use.
\end{DoxyItemize}
\item \#\#\# Local libraries can be found inside the lib folder, the following is a list of libraries and their uses.
\end{DoxyItemize}

\tabulinesep=1mm
\begin{longtabu}spread 0pt [c]{*{2}{|X[-1]}|}
\hline
\PBS\centering \cellcolor{\tableheadbgcolor}\textbf{ Name   }&\PBS\centering \cellcolor{\tableheadbgcolor}\textbf{ Description    }\\\cline{1-2}
\endfirsthead
\hline
\endfoot
\hline
\PBS\centering \cellcolor{\tableheadbgcolor}\textbf{ Name   }&\PBS\centering \cellcolor{\tableheadbgcolor}\textbf{ Description    }\\\cline{1-2}
\endhead
\mbox{\hyperlink{class_d_r_i0050}{DRI0050}}   &Manages the \mbox{\hyperlink{class_d_r_i0050}{DRI0050}} Pump PWM Controller    \\\cline{1-2}
\mbox{\hyperlink{class_d_s18_b20}{DS18\+B20}}   &Taken from Dane\textquotesingle{}s original project, this reads the temperature of a one-\/wire temperature sensor    \\\cline{1-2}
EEPPROM\+\_\+\+Manager   &contains an \mbox{\hyperlink{class_e_e_p_r_o_m___variable}{EEPROM\+\_\+\+Variable}} and Manager class that allows for easier read write access to EEPROM memory    \\\cline{1-2}
Simple\+\_\+\+Menu   &Contains a library that greatly simplifies menu creation and management, allows for variable modification and function calls   \\\cline{1-2}
\end{longtabu}

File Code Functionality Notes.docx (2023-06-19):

Autumn 2023 Algae Panel Project - Code Functionality Notes

Working:

- Infrared Receiver (IR) works with Remote Control for menu navigation.
- Solenoid Valve turns ON and OFF via Remote Control.
- Pump turns ON and OFF via Remote Control.
- Temperature Sensors show correct water temperature (data wire connected to pins 12 and 13 of the Arduino Mega).

Untested (but should work):

- Ultrasonic Sensor should work with the Yellow/Blue Cable (TX) connected to Pin 14 and the White/Green Cable (RX) connected to Pin 15 of the Arduino Mega, however untested.

Not currently working:

- LCD is unreliable. Potential fix:
  - Connect 4.7k – 10k pull-up resistors between the SDA + SCL lines and 5V. See circuit diagram below:

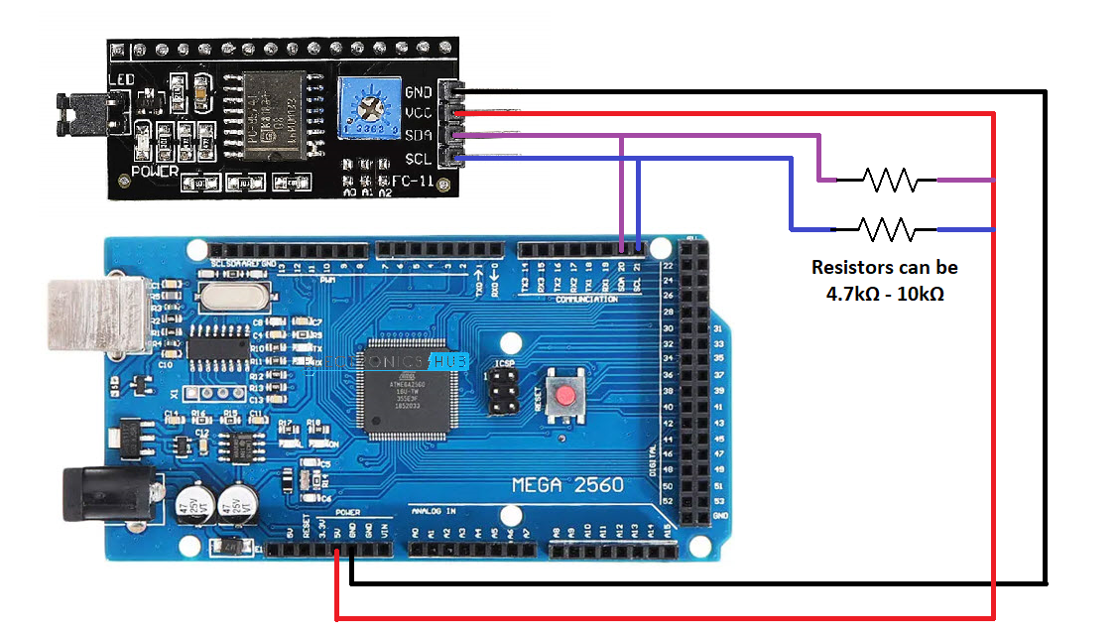
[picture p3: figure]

- No current working sensor to detect water level of panel:
  - Waterproof Ultrasonic Sensor (A02YYUW – same one as used in the Esky/Reservoir) does not physically fit in the panel.
  - Non-waterproof Ultrasonic Sensor (HC-SR04) unreliable – due to panel width being small, was very common for sensor to return a distance from the glass rather than the water surface.
  - Potential solutions:
    - IR Distance Sensor: Uses laser to get distance to a reflective surface. Problem: Water commonly doesn’t reflect the beam. In testing, the distance would sometimes measure the water surface, but would also sometimes measure through the water to the bottom, making it unreliable.
    - Float Switch: These will not indicate the level of the water but will act as a trigger if the water level gets too high, which can be used logically to turn off the pump and/or turn on the solenoid valve to help prevent overflow.

Unwritten:

- Currently no code in the main program to integrate temperature levels with pump + valve operation. This could be added as such:
  - // If temperature above threshold and Solenoid Valve is currently OFF, turn it ON. if(SolenoidState == Control_State::Off && Temp1Average >= MAX_THRESHOLD) { SolenoidState = Control_State::Manual; // Turn on Solenoid Valve

}

// Else if temperature is below threshold and the Solenoid Valve is ON, turn it OFF

else if(SolenoidState == Control_State::Manual && Temp1Average < MAX_THRESHOLD)

{

SolenoidState = Control_State::Off; // Turn off Solenoid Valve

}

// If temperature above threshold and pump is ON, turn it OFF

if(PumpState == Control_State::Manual && Temp1Average >= MAX_THRESHOLD)
{
PumpController.setPwmEnable(PWM_DISENABLE); // Turn off Pump Controller

}

// Else if temperature is below threshold, and there is water in the reservoir, and the pump is OFF, turn it ON

else if(PumpState == Control_State::Off && SonarAverage < DEPTH_THRESHOLD && Temp1Average < MAX_THRESHOLD)

{

PumpController.setPwmEnable(PWM_ENABLE); // Turn on Pump Controller

}

- Currently no code integrating level of reservoir with pump control. This could be added as such:
  - // If distance from sensor to reservoir water level is greater than some threshold, turn off pump (not enough water in reservoir)

if(SonarAverage > DEPTH_THRESHOLD && PumpState == Control_State::Manual)

{

PumpController.setPwmEnable(PWM_DISENABLE); // Turn on Pump Controller

}

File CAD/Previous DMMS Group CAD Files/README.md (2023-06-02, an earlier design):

READ ME

- files provided from previous DMMS group

- these are used in the assembly model for exploded view

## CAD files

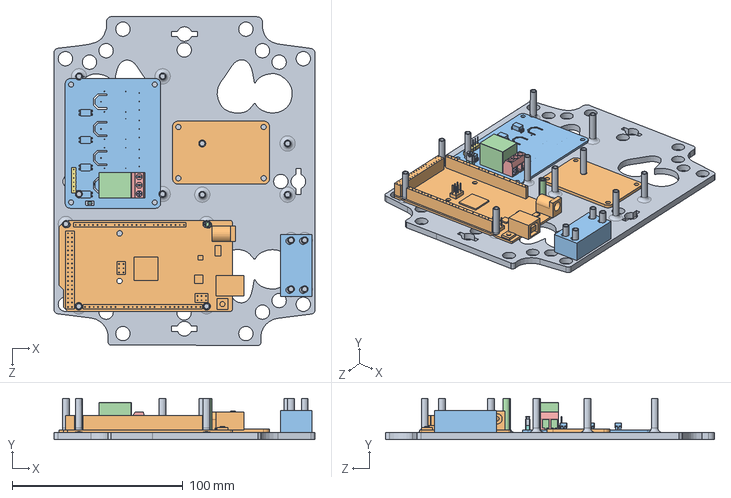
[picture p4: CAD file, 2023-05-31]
CAD/Interior Mount for Electrical Box/Practice Assembly1.SLDASM
152.9 x 24.2 x 192.8 mm
Interior Mount
silo - standoffs

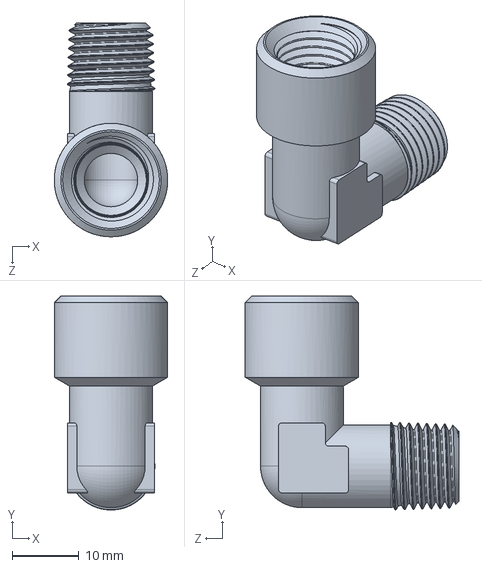
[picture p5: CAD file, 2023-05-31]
CAD/Plumbing/1. 8mm Male-Female Elbow Connector/8mm Male-Female Elbow Connector.SLDPRT
17.0 x 32.1 x 32.0 mm

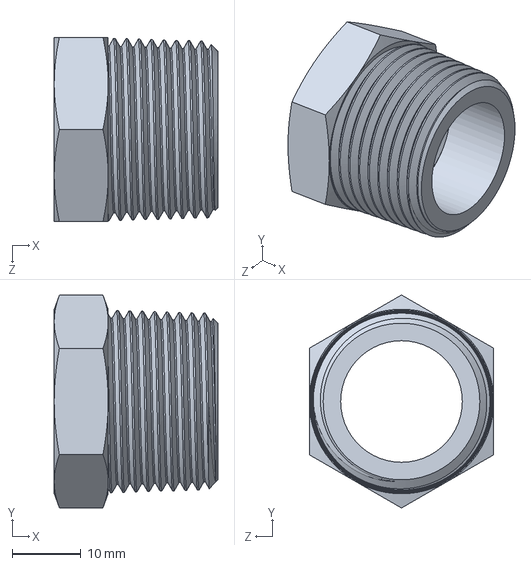
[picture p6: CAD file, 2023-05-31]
CAD/Plumbing/10. 15-20mm Female-Male Brass Reducing Bush/15-20mm Female-Male Brass Reducing Bush.SLDPRT
23.9 x 31.1 x 26.9 mm

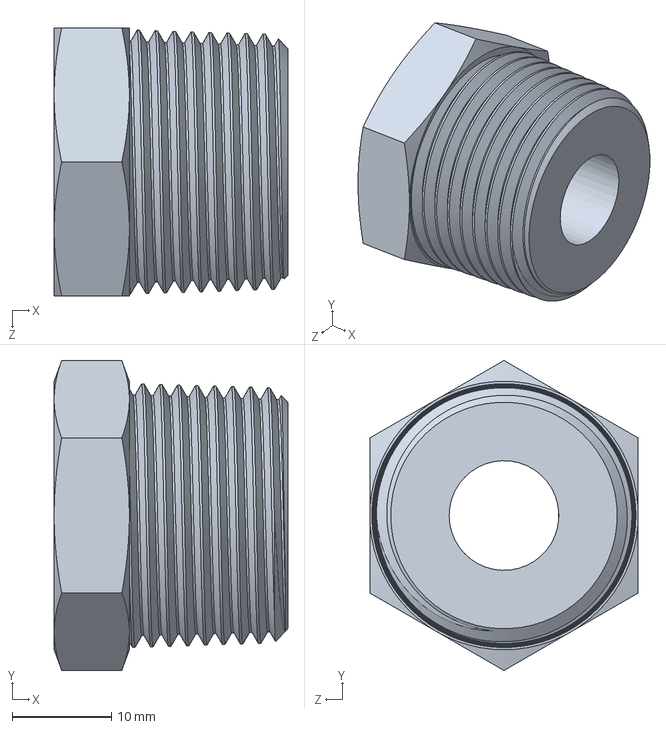
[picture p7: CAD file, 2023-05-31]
CAD/Plumbing/2. 8-20mm Female-Male Brass Reducing Bush/8-20mm Female-Male Brass Reducing Bush.SLDPRT
23.6 x 31.3 x 27.1 mm

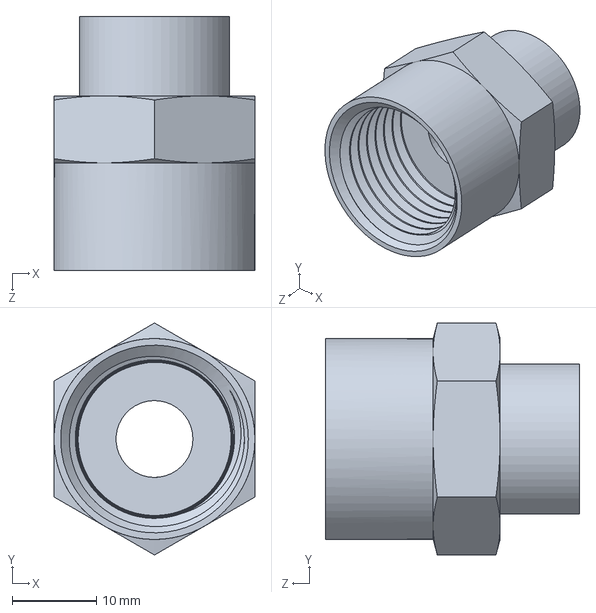
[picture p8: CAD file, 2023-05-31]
CAD/Plumbing/3. 8-15mm Brass Hex Socket/8-15mm Brass Hex Socket.SLDPRT
23.8 x 27.5 x 30.2 mm

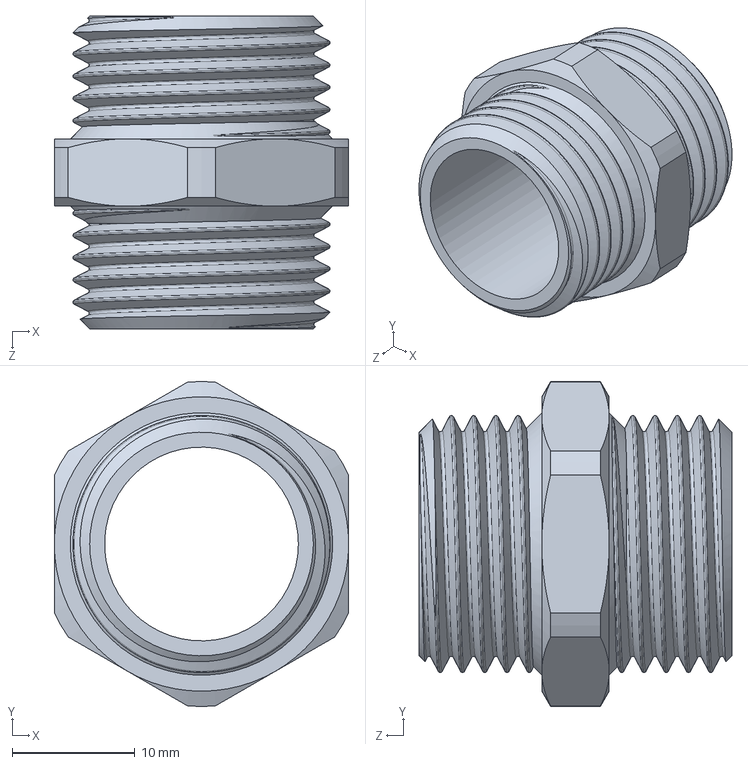
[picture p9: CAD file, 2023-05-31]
CAD/Plumbing/4. 15mm Brass Hex Nipple/15mm Brass Hex Nipple.SLDPRT
24.0 x 26.5 x 25.5 mm

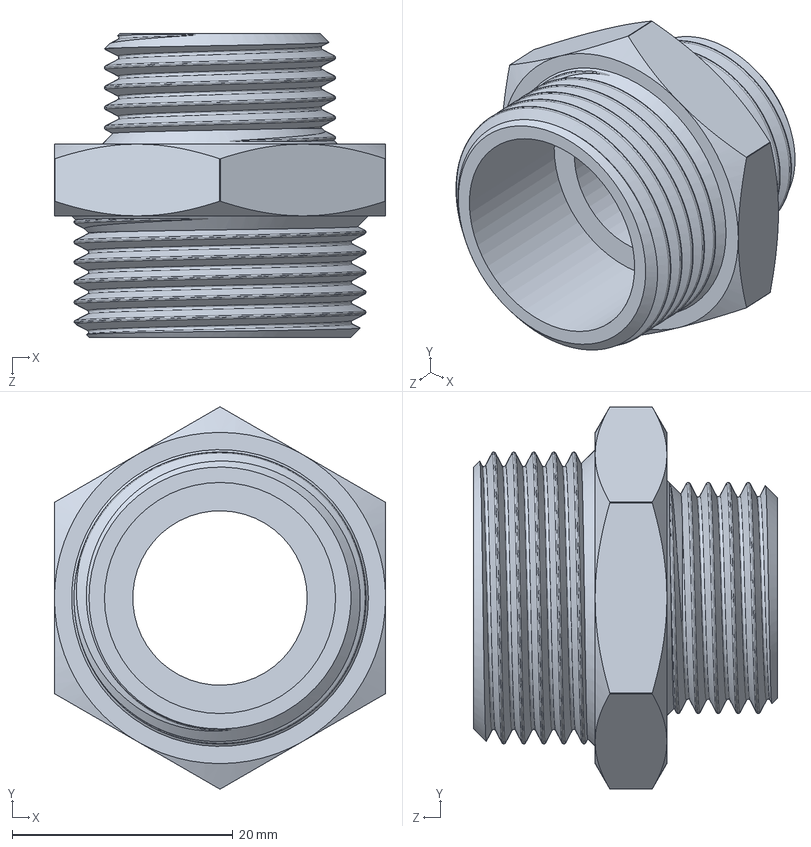
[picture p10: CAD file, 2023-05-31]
CAD/Plumbing/5. 15-20mm Brass Hex Nipple/15-20mm Brass Hex Nipple.SLDPRT
30.0 x 34.6 x 27.5 mm

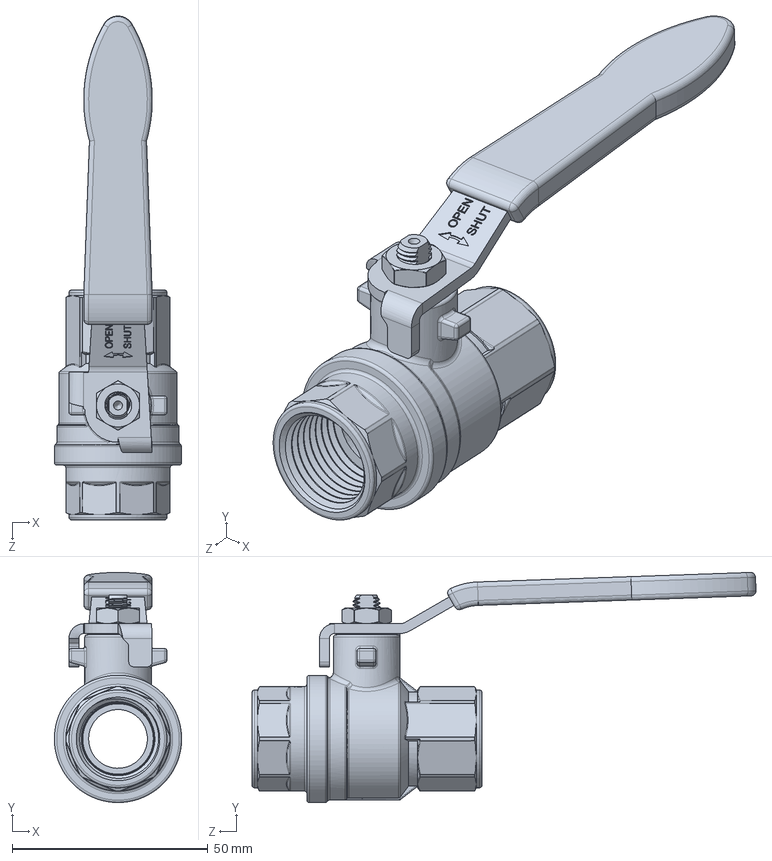
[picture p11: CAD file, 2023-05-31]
CAD/Plumbing/6. 15mm Brass Manual Ball Valve/15mm Brass Manual Ball Valve.SLDPRT
32.5 x 58.8 x 128.7 mm

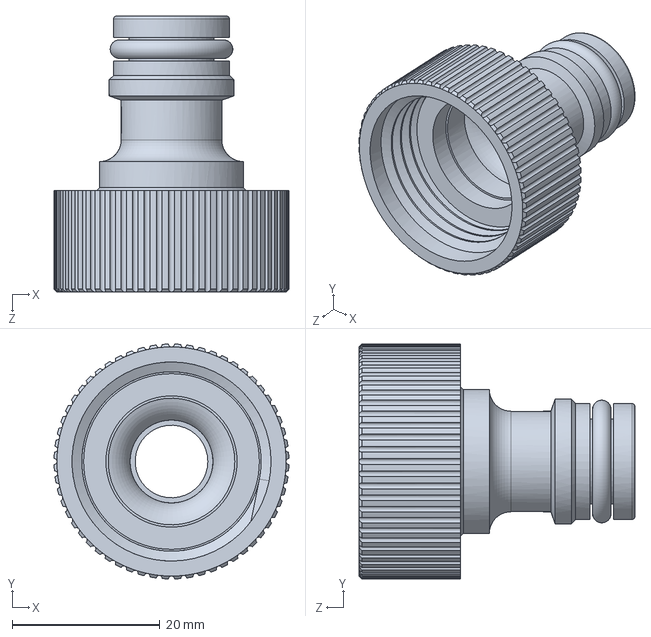
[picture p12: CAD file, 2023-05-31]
CAD/Plumbing/8. 20mm Tap Adaptor/20mm Tap Adaptor.SLDPRT
31.8 x 31.8 x 37.4 mm

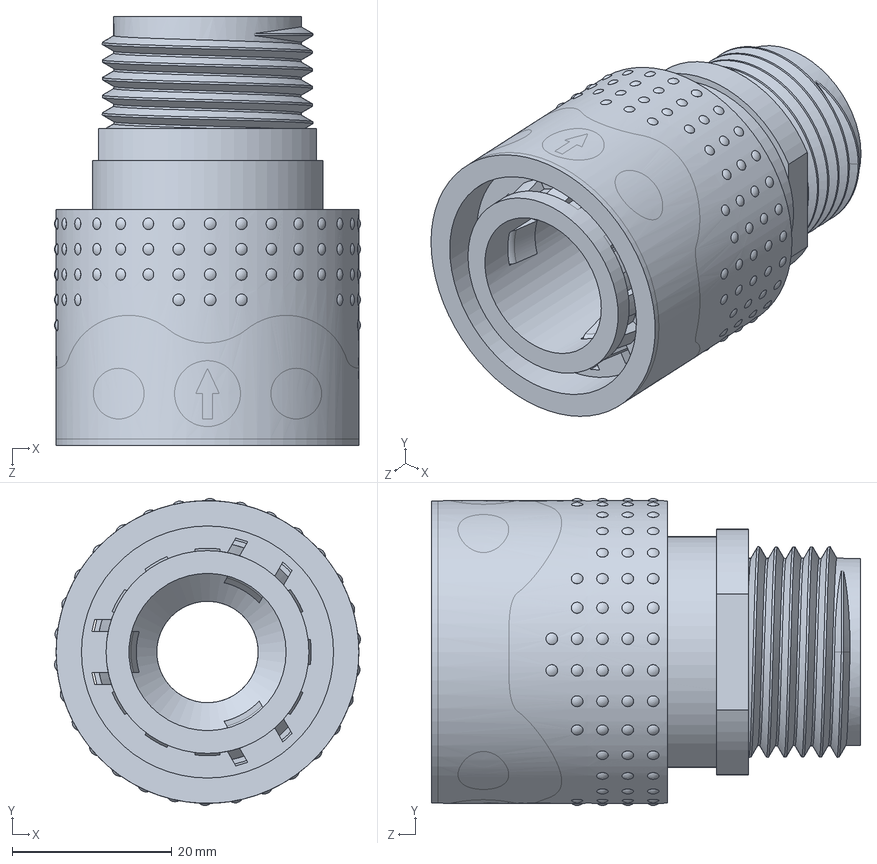
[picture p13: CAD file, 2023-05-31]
CAD/Plumbing/9. Hose Connector/Hose Connector.SLDPRT
38.3 x 38.5 x 53.8 mm

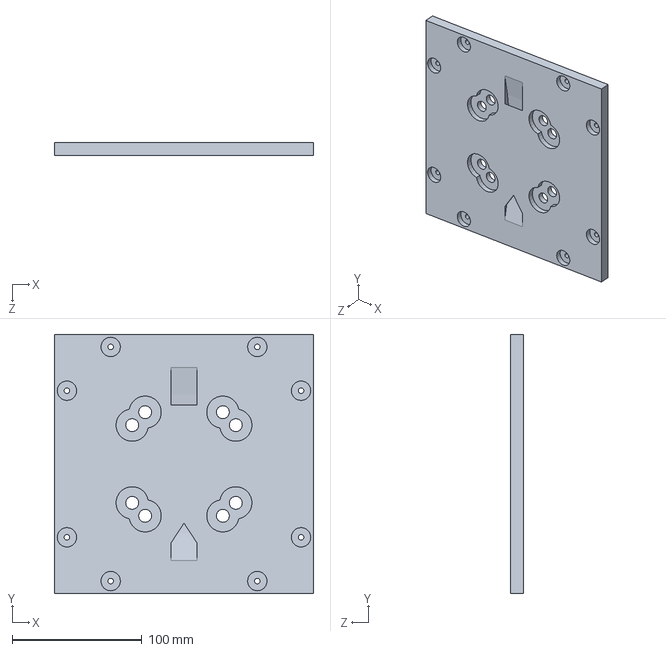
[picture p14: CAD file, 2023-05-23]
CAD/Pump__Elec_Mount/Universal Mounting Panel.SLDPRT
200.0 x 200.0 x 10.0 mm

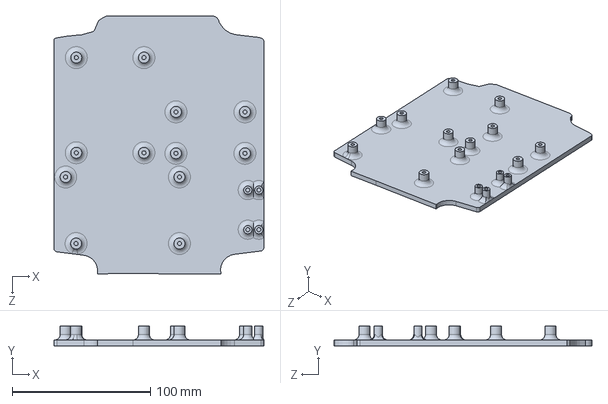
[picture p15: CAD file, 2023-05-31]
CAD/Interior Mount for Electrical Box/FIXED_inside_mount.SLDPRT
152.0 x 14.2 x 187.0 mm

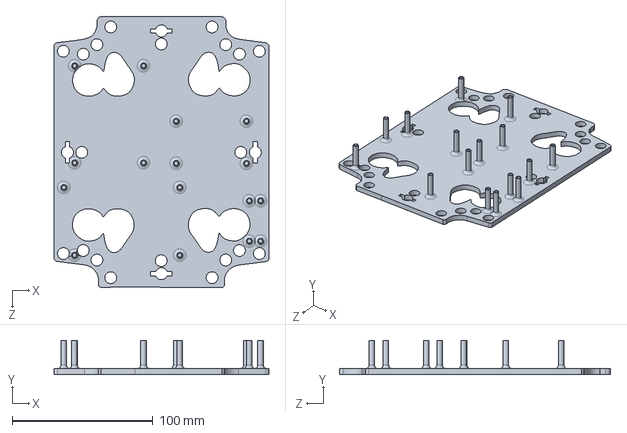
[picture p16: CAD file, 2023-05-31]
CAD/Interior Mount for Electrical Box/Interior Mount.SLDPRT
152.9 x 24.2 x 192.8 mm

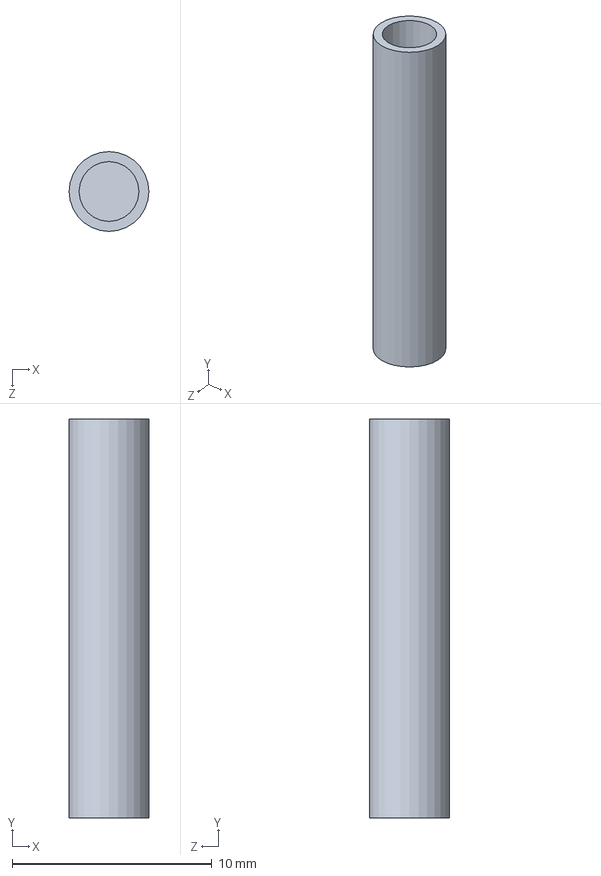
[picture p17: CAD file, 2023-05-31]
CAD/Interior Mount for Electrical Box/silo - standoffs.SLDPRT
4.00 x 20.0 x 4.00 mm

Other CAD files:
CAD/GrabCad Models of Electricals/4 Channel No Name Relay Parts/Relay - 4 Ch - 5v Montaj.SLDASM
CAD/GrabCad Models of Electricals/Relay - 4 Ch - 5v Montaj.SLDASM
CAD/GrabCad Models of Electricals/4 Channel No Name Relay Parts/Metal Clamp Part.SLDPRT
CAD/GrabCad Models of Electricals/arduinoMega.SLDPRT
CAD/CAD Models for Dane/FINAL_PLUMBING_CAD_WIP.SLDDRW
CAD/GrabCad Models of Electricals/4 Channel No Name Relay Parts/2 Header.SLDPRT
CAD/GrabCad Models of Electricals/4 Channel No Name Relay Parts/4 Ch - 5v Relay Board.SLDPRT
CAD/GrabCad Models of Electricals/4 Channel No Name Relay Parts/6 Header.SLDPRT
CAD/GrabCad Models of Electricals/4 Channel No Name Relay Parts/Clamp Body.SLDPRT
CAD/GrabCad Models of Electricals/4 Channel No Name Relay Parts/Jumper.SLDPRT
CAD/GrabCad Models of Electricals/4 Channel No Name Relay Parts/Relay Body.SLDPRT
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

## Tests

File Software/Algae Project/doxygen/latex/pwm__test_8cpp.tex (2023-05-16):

\hypertarget{pwm__test_8cpp}{}\doxysection{src/functional\+\_\+tests/pwm\+\_\+test.cpp File Reference}
\label{pwm__test_8cpp}\index{src/functional\_tests/pwm\_test.cpp@{src/functional\_tests/pwm\_test.cpp}}
{\ttfamily \#include $<$Arduino.\+h$>$}\newline
\doxysubsection*{Functions}
\begin{DoxyCompactItemize}
\item 
void \mbox{\hyperlink{pwm__test_8cpp_a4fc01d736fe50cf5b977f755b675f11d}{setup}} ()
\item 
void \mbox{\hyperlink{pwm__test_8cpp_afe461d27b9c48d5921c00d521181f12f}{loop}} ()
\end{DoxyCompactItemize}
\doxysubsection*{Variables}
\begin{DoxyCompactItemize}
\item 
const int \mbox{\hyperlink{pwm__test_8cpp_a0ea5664a78e8e4e49912e8c9c1af5bbf}{pwm\+\_\+pin}} = 3
\item 
const float \mbox{\hyperlink{pwm__test_8cpp_ac9ad91ee9acffd7e12f9826341a10512}{duty\+\_\+cycle}} = 50
\end{DoxyCompactItemize}

\doxysubsection{Function Documentation}
\mbox{\Hypertarget{pwm__test_8cpp_afe461d27b9c48d5921c00d521181f12f}\label{pwm__test_8cpp_afe461d27b9c48d5921c00d521181f12f}} 
\index{pwm\_test.cpp@{pwm\_test.cpp}!loop@{loop}}
\index{loop@{loop}!pwm\_test.cpp@{pwm\_test.cpp}}
\doxysubsubsection{\texorpdfstring{loop()}{loop()}}
{\footnotesize\ttfamily void loop (\begin{DoxyParamCaption}{ }\end{DoxyParamCaption})}

\mbox{\Hypertarget{pwm__test_8cpp_a4fc01d736fe50cf5b977f755b675f11d}\label{pwm__test_8cpp_a4fc01d736fe50cf5b977f755b675f11d}} 
\index{pwm\_test.cpp@{pwm\_test.cpp}!setup@{setup}}
\index{setup@{setup}!pwm\_test.cpp@{pwm\_test.cpp}}
\doxysubsubsection{\texorpdfstring{setup()}{setup()}}
{\footnotesize\ttfamily void setup (\begin{DoxyParamCaption}{ }\end{DoxyParamCaption})}

\doxysubsection{Variable Documentation}
\mbox{\Hypertarget{pwm__test_8cpp_ac9ad91ee9acffd7e12f9826341a10512}\label{pwm__test_8cpp_ac9ad91ee9acffd7e12f9826341a10512}} 
\index{pwm\_test.cpp@{pwm\_test.cpp}!duty\_cycle@{duty\_cycle}}
\index{duty\_cycle@{duty\_cycle}!pwm\_test.cpp@{pwm\_test.cpp}}
\doxysubsubsection{\texorpdfstring{duty\_cycle}{duty\_cycle}}
{\footnotesize\ttfamily const float duty\+\_\+cycle = 50}

\mbox{\Hypertarget{pwm__test_8cpp_a0ea5664a78e8e4e49912e8c9c1af5bbf}\label{pwm__test_8cpp_a0ea5664a78e8e4e49912e8c9c1af5bbf}} 
\index{pwm\_test.cpp@{pwm\_test.cpp}!pwm\_pin@{pwm\_pin}}
\index{pwm\_pin@{pwm\_pin}!pwm\_test.cpp@{pwm\_test.cpp}}
\doxysubsubsection{\texorpdfstring{pwm\_pin}{pwm\_pin}}
{\footnotesize\ttfamily const int pwm\+\_\+pin = 3}

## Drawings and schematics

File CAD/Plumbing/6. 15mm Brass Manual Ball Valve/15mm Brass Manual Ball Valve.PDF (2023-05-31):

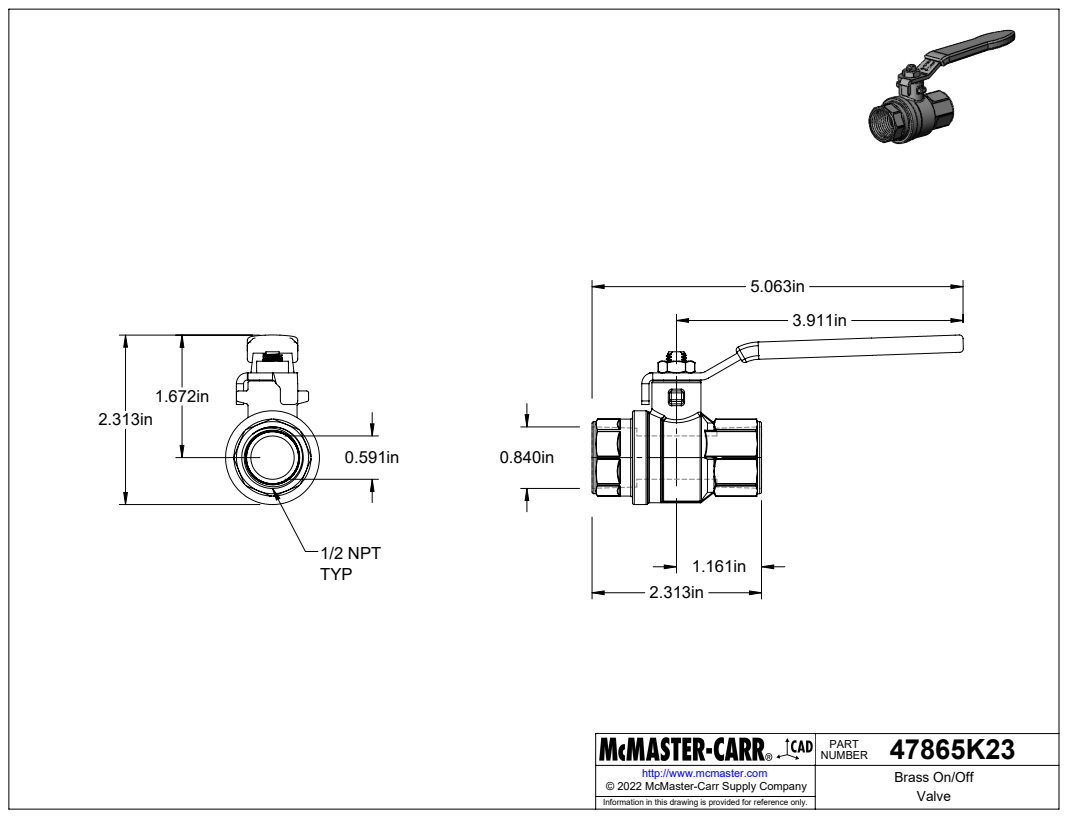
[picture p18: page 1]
1/2 NPT

47865K23 PART NUMBER

http://www.mcmaster.com | Brass On/Off Valve © 2022 McMaster-Carr Supply Company

Information in this drawing is provided for reference only.

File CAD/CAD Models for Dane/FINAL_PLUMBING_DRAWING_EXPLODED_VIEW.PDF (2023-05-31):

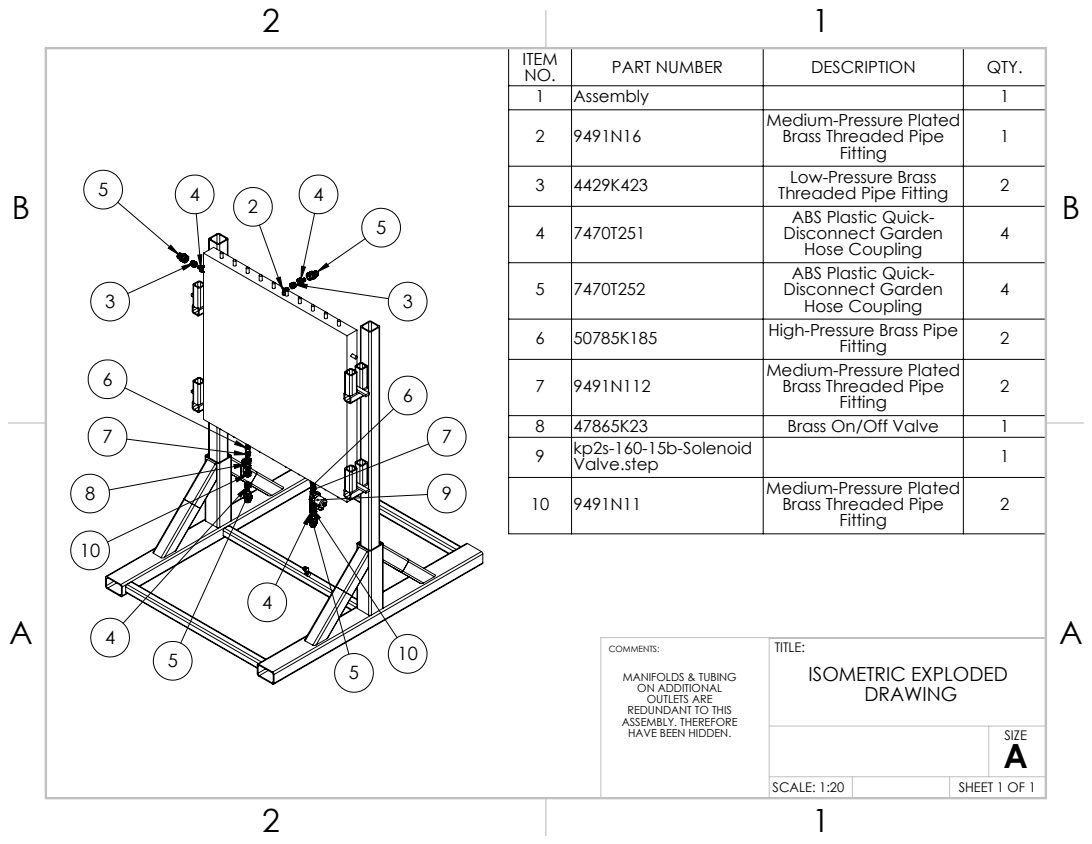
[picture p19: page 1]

ITEM
NO. | 9491N16 Assembly PART NUMBER | DESCRIPTION | QTY. 1 1 2

Medium-Pressure Plated Brass Threaded Pipe Fitting | 1

3 | 4429K423 | Low-Pressure Brass Threaded Pipe Fitting | 2
4 | 7470T251 | ABS Plastic Quick-Disconnect Garden Hose Coupling | 4

5 | 7470T252 | ABS Plastic Quick-Disconnect Garden Hose Coupling | 4

6 | 50785K185 | High-Pressure Brass Pipe Fitting | 2
7 | 9491N112 | Medium-Pressure Plated Brass Threaded Pipe Fitting | 2

8 | 47865K23 | Brass On/Off Valve | 1
9 | kp2s-160-15b-Solenoid Valve.step | | 1
10 | 9491N11 | Medium-Pressure Plated Brass Threaded Pipe Fitting | 2

COMMENTS: MANIFOLDS & TUBING ON ADDITIONAL OUTLETS ARE REDUNDANT TO THIS ASSEMBLY. THEREFORE HAVE BEEN HIDDEN. | TITLE: ISOMETRIC EXPLODED DRAWING

SIZE A

SCALE: 1:20 | | SHEET 1 OF 1

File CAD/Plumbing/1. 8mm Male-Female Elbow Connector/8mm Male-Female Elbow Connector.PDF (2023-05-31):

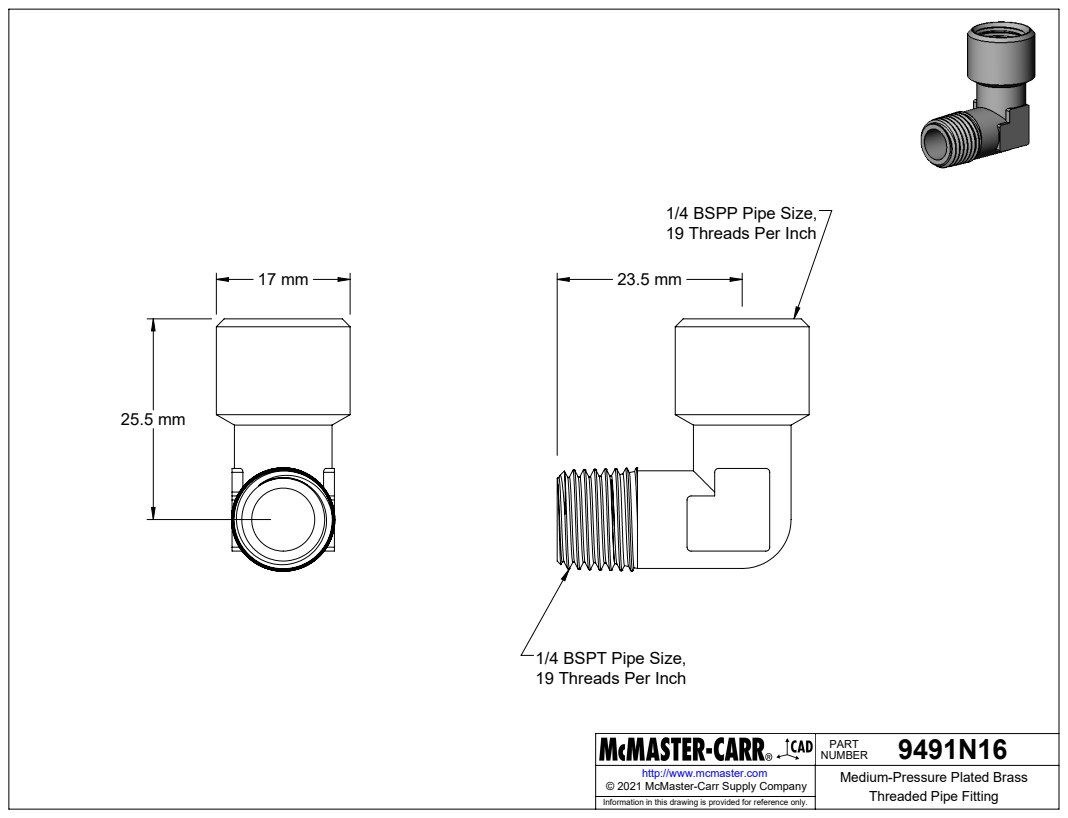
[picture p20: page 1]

1/4 BSPP Pipe Size,
19 Threads Per Inch

1/4 BSPT Pipe Size,

9491N16 PART NUMBER

http://www.mcmaster.com | Medium-Pressure Plated Brass Threaded Pipe Fitting © 2021 McMaster-Carr Supply Company

Information in this drawing is provided for reference only.

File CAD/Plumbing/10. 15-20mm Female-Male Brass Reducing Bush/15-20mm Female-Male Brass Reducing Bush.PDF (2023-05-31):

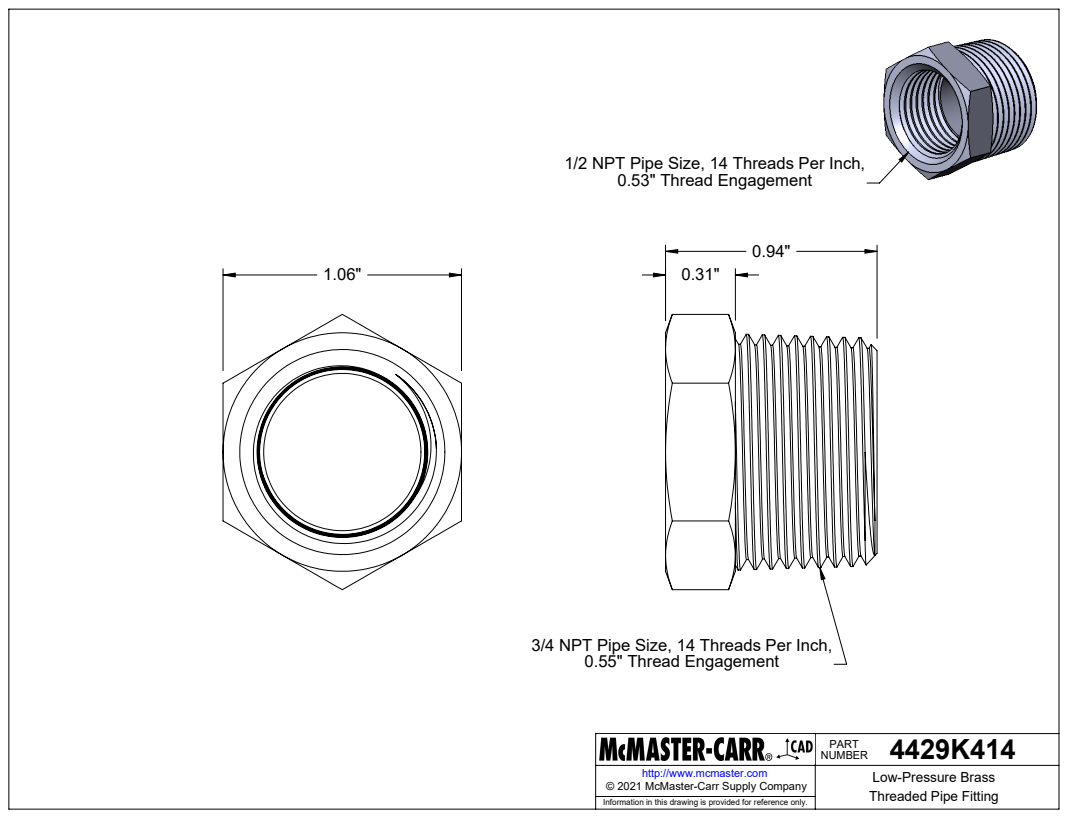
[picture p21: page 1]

1/2 NPT Pipe Size, 14 Threads Per Inch,
0.53" Thread Engagement

3/4 NPT Pipe Size, 14 Threads Per Inch,
0.55" Thread Engagement

4429K414 PART NUMBER

http://www.mcmaster.com | Low-Pressure Brass Threaded Pipe Fitting © 2021 McMaster-Carr Supply Company

Information in this drawing is provided for reference only.

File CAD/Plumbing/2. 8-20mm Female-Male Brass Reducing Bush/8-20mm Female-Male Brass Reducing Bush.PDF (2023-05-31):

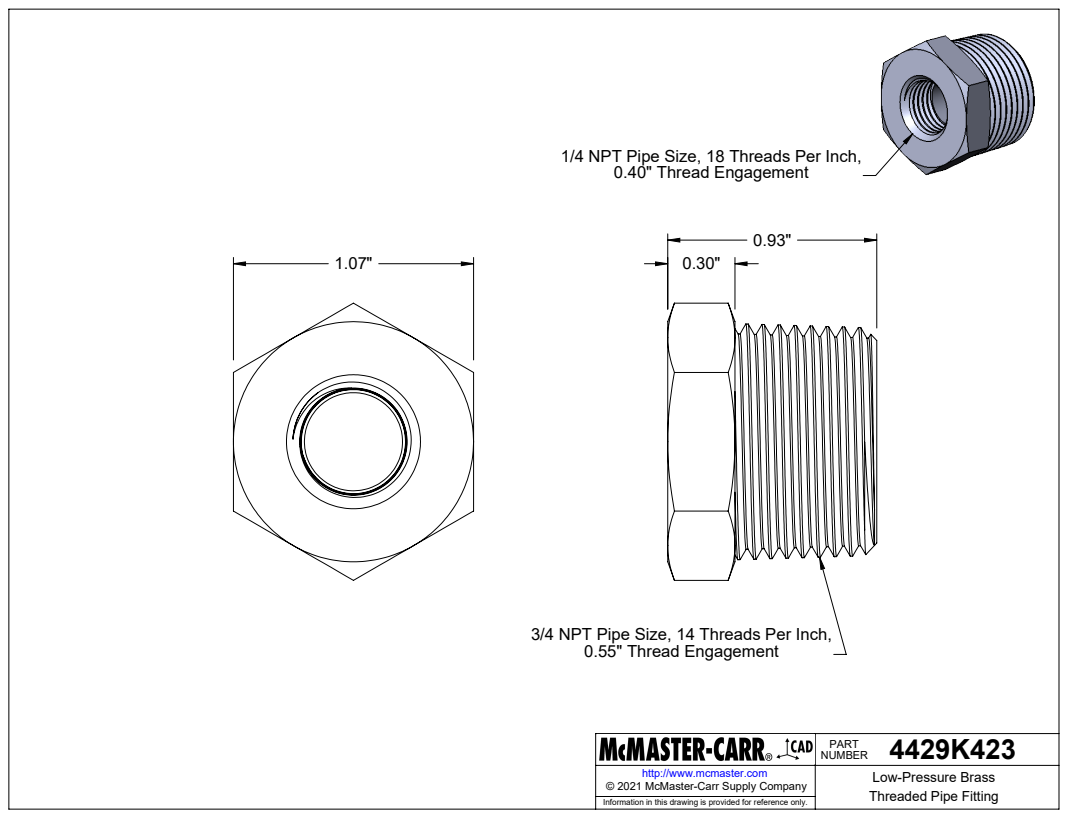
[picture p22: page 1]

1/4 NPT Pipe Size, 18 Threads Per Inch,
0.40" Thread Engagement

3/4 NPT Pipe Size, 14 Threads Per Inch,
0.55" Thread Engagement

4429K423 PART NUMBER

http://www.mcmaster.com | Low-Pressure Brass Threaded Pipe Fitting © 2021 McMaster-Carr Supply Company

Information in this drawing is provided for reference only.

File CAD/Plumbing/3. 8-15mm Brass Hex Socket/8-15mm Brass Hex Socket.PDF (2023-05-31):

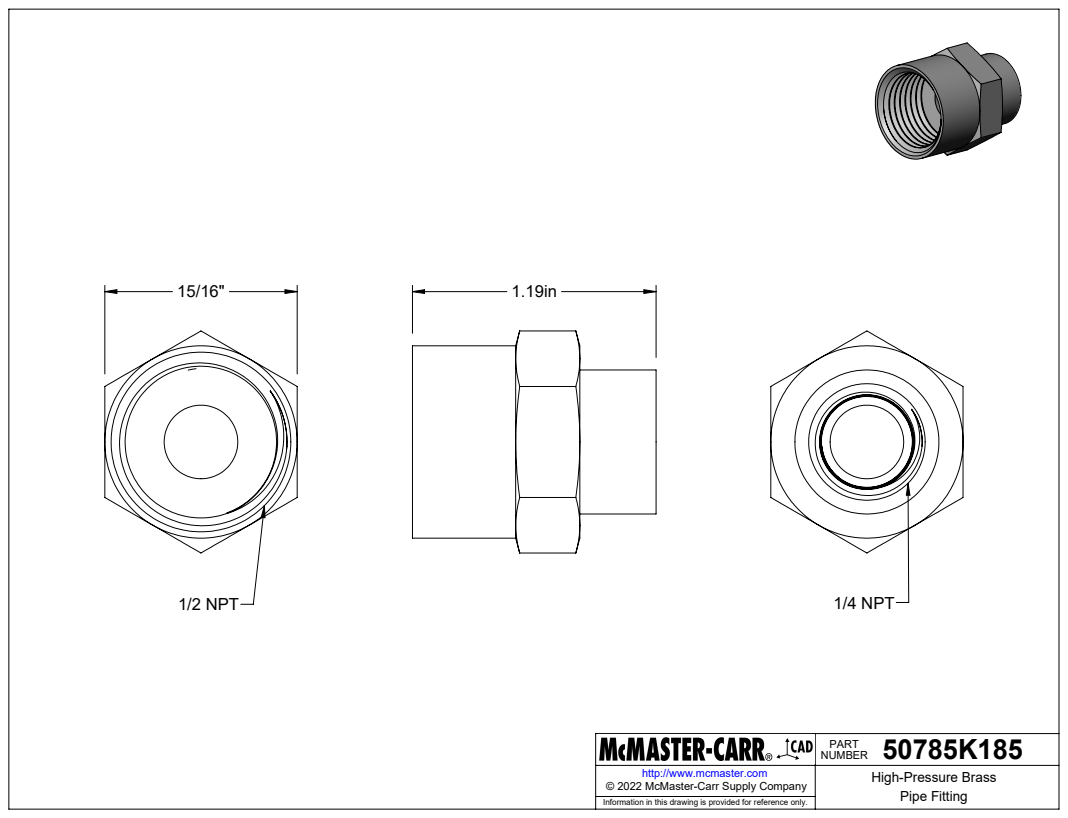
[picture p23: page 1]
1/4 NPT; 1/2 NPT

50785K185 PART NUMBER

http://www.mcmaster.com | High-Pressure Brass Pipe Fitting © 2022 McMaster-Carr Supply Company

Information in this drawing is provided for reference only.

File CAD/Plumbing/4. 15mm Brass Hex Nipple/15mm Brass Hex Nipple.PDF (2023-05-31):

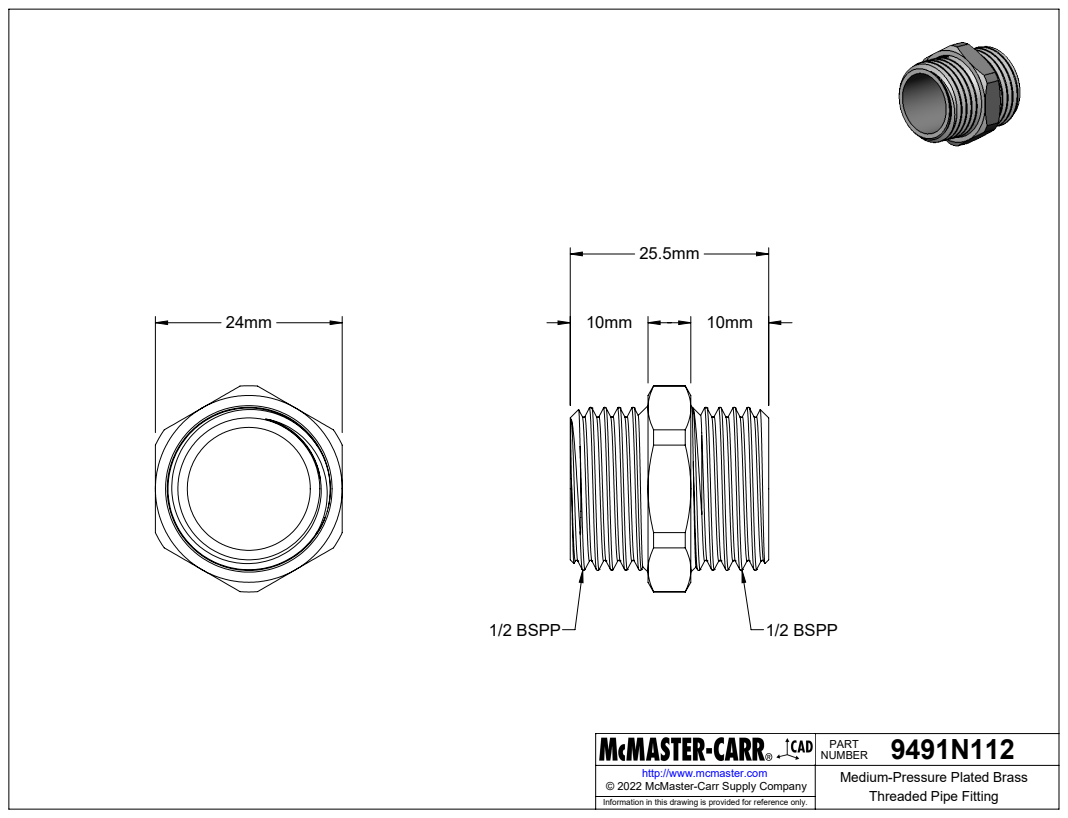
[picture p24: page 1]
1/2 BSPP

9491N112 PART NUMBER

http://www.mcmaster.com | Medium-Pressure Plated Brass Threaded Pipe Fitting © 2022 McMaster-Carr Supply Company

Information in this drawing is provided for reference only.

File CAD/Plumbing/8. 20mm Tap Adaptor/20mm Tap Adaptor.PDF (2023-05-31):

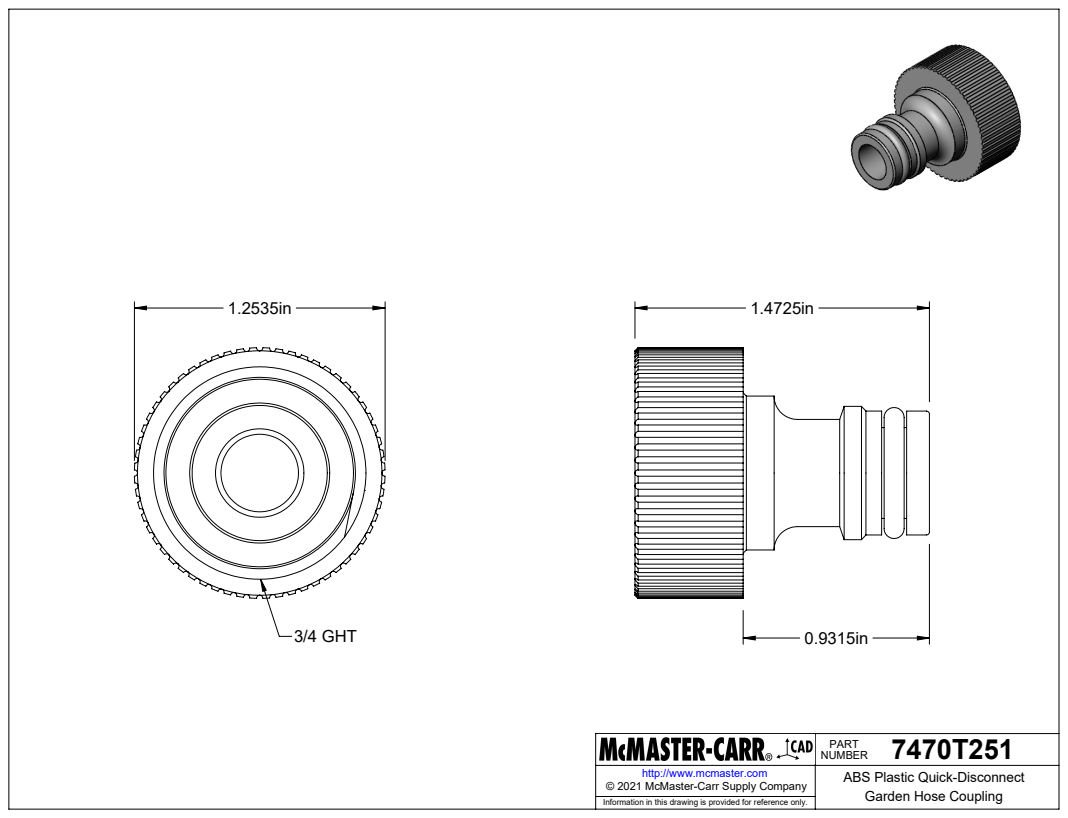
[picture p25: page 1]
3/4 GHT

7470T251 PART NUMBER

http://www.mcmaster.com | ABS Plastic Quick-Disconnect Garden Hose Coupling © 2021 McMaster-Carr Supply Company

Information in this drawing is provided for reference only.

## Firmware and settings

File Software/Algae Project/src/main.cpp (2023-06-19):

/**
 * @file main.cpp
 * @author Sebastian Schroder, Adam Scicluna
 * @brief Main file, to run either select the main or mainmega environments inside platformio
 * main may not run due to the large size of the menu inside @file menu.h
 * @version 0.1
 * @date 2023-06-02
 * 
 * @copyright Copyright (c) 2023
 * 
 */

// Including necessary libraries, including self-created consisting other information
#include <Wire.h>
#include <global_variables.h>
#include <Arduino.h>
#include <IRremote.h> //this needs to be included in a .cpp file, IDK why it doesn't work in a header file

// Function Declarations
void Update_Sensor_State();
void Update_Control_State();

// Sensor variable intialisations
DS18B20 TempSensor1(TSensorPin1);
DS18B20 TempSensor2(TSensorPin2);
SEN0311 Sonar1(SonarRXPin,SonarTXPin);
// NewPing Sonar1(SSensorPin1,SonarEchoPin,400);
// NewPing Sonar2(SSensorPin2,SonarEchoPin,400);
IRrecv irrecv(IRRXPin);
DRI0050 PumpController(PumpTxPin,PumpRxPin);

// Setup loop runs once - for intialisation of Serial, LCD, and I/O Pins
void setup() {
  
  // Initialise Serial at 9600 BAUD Rate
  Serial.begin(9600);

  // Start LCD and IR Receiver
  Serial.println("Starting Up");
  delay(100);
  lcd.init();
  lcd.clear();
  lcd.backlight();
  // lcd.begin(16,2);
  TopMenu.begin(display,displayValue);
  PumpController.setPwmFreq(10);
  PumpController.setPwmDuty(0);
  irrecv.enableIRIn(); // starts interrupt for IR receiver
  // if you want to change values here in code, then comment out the retrieve call and save the changes to the arduino
  // rom_manager.Retrieve();

  // Initialise PinMode for the Solenoid Valve Relay COM Port
  pinMode(SolanoidPin1,OUTPUT);

}

// Loop function - runs continously unless interrupted
void loop() {
// ----------------------------------------     UI      ---------------------------------------------------------

  if(irrecv.decode()){ //if IR receiver is picking up something
      if(Menu_IR_Input(irrecv.decodedIRData.command)){// if the response is a recognised command delay to prevent multiple commands read
        delay(20);
        irrecv.printIRResultMinimal(&Serial);
      irrecv.resume();
    }
  }
  if(Serial.available()){
    Menu_Serial_Input(Serial.read());
  }

//--------------------------------------------------      Sensor Data     ----------------------------------------------------------
  if(millis()-lastSensorUpdate >=SENSOR_RATE){Update_Sensor_State();}
//----------------------------------------------------    Control   -----------------------------------------------
  if(millis()-lastStateUpdate >= STATE_RATE){Update_Control_State();}
}


/*
  Function Defintion: Sensor Updates
  Purpose: Takes Sensor readings, adds them to a cyclic array, and averages
           the array (currently set to store the last 10 readings) to print
           to LCD screen.
*/
void Update_Sensor_State(){
  lastSensorUpdate = millis();
  Serial.println("Reading Sensors");
  Serial.print("sonar: ");
  Serial.println(Sonar1.get_dist());

  Temp1[Cyclic_Array_Index] = (int)TempSensor1.readTempC();
  Temp2[Cyclic_Array_Index] = (int)TempSensor2.readTempC();
  SonarDist1[Cyclic_Array_Index] = (int)Sonar1.get_dist();
  // IRDist2[Cyclic_Array_Index] = Sonar2.get_dist(); //! need to swap to using the IR object
  Cyclic_Array_Index++;
  Temp1Average = Average_Array(Temp1,Cyclic_Array_Size);
  Temp2Average = Average_Array(Temp2,Cyclic_Array_Size);
  SonarAverage = Average_Array(SonarDist1,Cyclic_Array_Size);
  if(Cyclic_Array_Index>=Cyclic_Array_Size){Cyclic_Array_Index=0;}
}

/*
  Function Definition: Update state of controls (pump + solenoid valve)
  Purpose: Based on the sensor readings, and the set pump flow-rate, this function
           assigns a number, also known as a 'state' to each of the pump and
           solenoid valve to determine its current operation (e.g. on or off).
*/
void Update_Control_State()
{
  lastStateUpdate=millis();
  Serial.print("Pumpstate: ");
  Serial.print(PumpState);
  Serial.print(" , SolanoidState: ");
  Serial.println(SolanoidState);
  if(PumpState != prevPumpState)
  {
    prevPumpState=PumpState;
    if(PumpState==Control_State::Off)
    {  
      // if the pumpstate is off then turn off the pump pwm controller
      PumpController.setPwmEnable(PWM_DISENABLE);
      //digitalWrite(SolanoidPin2,LOW); //this is
      Serial.println("Pump Off");           
    }

    if(PumpState==Control_State::Manual)
    { 
      // if the state is set to manual, 
      PumpController.setPwmDuty(manual_dutycycle.var);
      PumpController.setPwmEnable(PWM_ENABLE);
      Serial.print("Pump On, duty Cycle: ");
      Serial.println(manual_dutycycle.var);
      //digitalWrite(SolanoidPin2,HIGH);
    }           
  }

  if(SolanoidState!=prevSolanoidState)
  {
    prevSolanoidState=SolanoidState;
    if(SolanoidState==Control_State::Off)
    {
      //digitalWrite(SolanoidPin1,LOW);
      //digitalWrite(SolanoidPin2,LOW);
      //digitalWrite(26,LOW);
      digitalWrite(28,LOW);
      Serial.println("Solenoid Closed");
    }
    else if(SolanoidState==Control_State::Manual)
    {
      //digitalWrite(SolanoidPin1,HIGH);
      //digitalWrite(SolanoidPin2,HIGH);
      //digitalWrite(26,HIGH);
      digitalWrite(28,HIGH);
      Serial.println("Solenoid Open");
    }       
  }


  if(SolanoidState==Control_State::Automatic)
  {
          
  }


  if(PumpState==Control_State::Automatic)
  {

  }
}

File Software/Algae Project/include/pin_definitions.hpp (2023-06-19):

/**
 * @file pin_definitions.hpp
 * @author Sebastian Schroder
 * @brief Use this document to define all Pins used in the main code in the menu.cpp file inside the Menu_IR_Input function
 * @version 0.1
 * @date 2023-06-02
 * 
 * @copyright Copyright (c) 2023
 *  
 */

#ifndef PIN_DEFINITIONS_H
#define PIN_DEFINITIONS_H
#include <Arduino.h>






// --------------------------       SENSORS     ------------------------------
# define TSensorPin1 12
#define TSensorPin2 13
#define SonarTXPin 14    // Prev A3 : YELLOW/BLUE CABLE - 3RD CABLE
#define SonarRXPin 15    // Prev A2 : WHITE/GREEN CABLE - 4TH CABLE



//------------------------------        CONTROL     --------------------------------
#define PumpTxPin 9
#define PumpRxPin 10

#define SolanoidPin1 28
#define SolanoidPin2 24 // emergency pin for use with the pump until the pwm motor controller board arrives 


//------------------------------        UI      ------------------------------

#define IRRXPin 11


// ----------------------------     DEPRECATED      ---------------------------------
// #define xinput  A0
// #define yinput = A1
// #define Button = 8

#endif

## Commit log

2023-05-01 added pump and solanoid control
2023-05-02 attempted to solve memmory issue with menu and rtos conflict. was unable to solve satisfactory thus moving to arduino mega for larger memory size
    [joystick_test.cpp, main.cpp, menu.cpp]
2023-05-02 added DRI0050 & Ultrasonic tests
2023-05-07 fixes to DRI test
    [DRI0050_test.cpp, solanoid_test.cpp]
2023-05-08 changed pin variables to definitions to save on memory
2023-05-11 swapped from rtos to simpler model to allow for easier future implementations
    [main.cpp, menu.cpp, pin_definitions.hpp]
2023-05-16 removed unnecessary files, added documentation, READMEs and media folder
    [Universal Mounting Panel.SLDPRT]
2023-05-23 updated cad mount model
    [Universal Mounting Panel.SLDPRT, Universal Mounting Panel.STL]
2023-05-31 swapped to I2C LCD
    [main.cpp, menu.cpp, pin_definitions.hpp]
2023-06-02 changed folder structure
    [15-20mm Brass Hex Nipple.SLDPRT, 15-20mm Female-Male Brass Reducing Bush.SLDPRT, 15mm Brass Hex Nipple.SLDPRT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]
2023-06-07 Scic Ultrasonic Sensor Test
    A02YYUW Waterproof Ultrasonic Sensor Test working individually -> sen0311_test_scic.cpp
2023-06-07 Commenting US Test
    Commenting on Ultrasonic Sensor Test so we don't forget which pin in TX and RX
2023-06-07 Updating Seb Ultrasonic Test
    Fixed SEN0311_test.cpp to not return errors. Used Uno for testing - data pins 6 and 7 for TX and RX cable respectively
    [SEN0311_test.cpp]
2023-06-07 Edit main + pin definitions for Ultrasonic Sensors
    Changed pin definition names for Ultrasonic Sensors + updated them in main file - set TX and RX to Pins 6 and 7 (prev A3 and A2)
2023-06-13 Updating LCD, US and Main + Adding Comments
    Updates for LCD:
    - A test file, which will find the I2C address it is communicating on, and validate this (depends on IC manufacturer).
    - Updating declaration of LCD in 'global_variables' to include Address (default 0x27), LCD Rows and Columns (16 x 2)
    Updates for Ultrasonic Sensor (US):
    - Fixed the 'get_dist' function in SEN0311 class to return in cm.
    - Swapped around the TX, RX arguments in the constructor to match the SoftwareSerial constructor
    Updates for Main:
    - Added a Cyclic Array to track Ultrasonic Sensor distance values.
    - Average the array described above to get an averaged distance to display.
    Added comments for brevity and clarity o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
    [lcd_i2c_test_scic.cpp, main.cpp, menu.cpp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]
2023-06-19 Pushing final changes based on 'Code Functionality Notes' word document
    Uploading 'Code Functionality Notes' document with further code documentation, and the respective code based on its outline (solenoids, ultrasonic sensors, etc).
